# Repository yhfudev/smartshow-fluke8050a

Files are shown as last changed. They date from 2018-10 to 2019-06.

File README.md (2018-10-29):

SmartShow
=========

SmartShow implemented a digital interface to the vintage Fluke 8050a DMM,
fetches the display data via UART port, and optional connected by WiFi via an ESP8266 module.

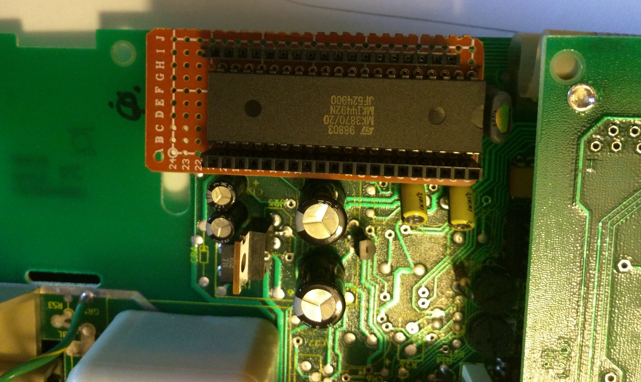
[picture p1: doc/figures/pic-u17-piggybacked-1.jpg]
Piggybacked


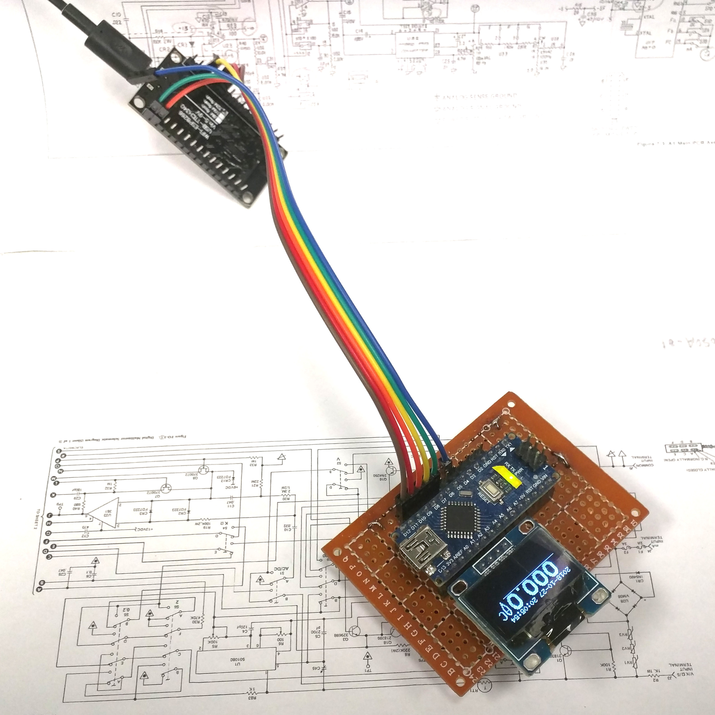
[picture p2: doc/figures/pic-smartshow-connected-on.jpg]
Connected ESP


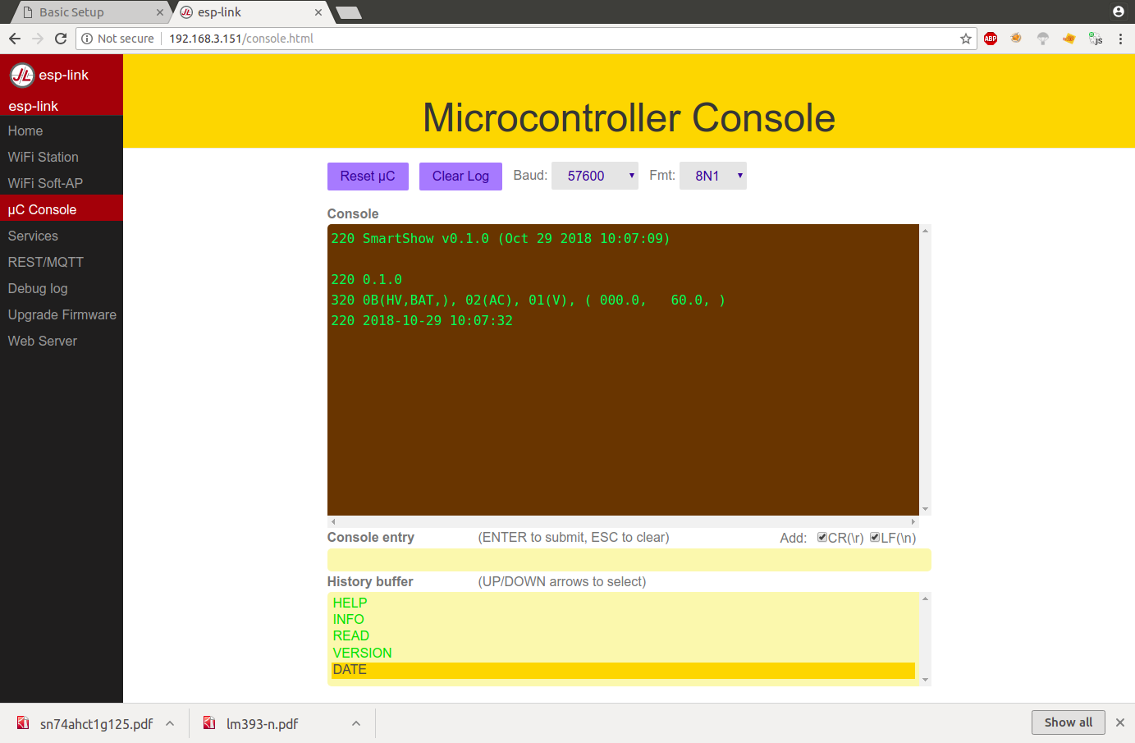
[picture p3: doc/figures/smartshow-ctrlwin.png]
Command line


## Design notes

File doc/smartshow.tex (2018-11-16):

%# -*- coding: utf-8 -*-
% !TeX encoding = UTF-8 Unicode
% !TeX spellcheck = en_US
% !TeX TS-program = xelatex
%~ \XeTeXinputencoding "UTF-8"
% vim:ts=4:sw=4
%
% 以上设定默认使用 XeLaTex 编译，并指定 Unicode 编码，供 TeXShop 自动识别

\newcommand{\doctitle}{SmarShow User Manual}
\newcommand{\docauthor}{Yunhui Fu}
\newcommand{\dockeywords}{}
\newcommand{\docsubject}{}

\documentclass[a4paper,10pt]{article}

\title{\doctitle}
\author{\docauthor}
\date{}

\usepackage{ifthen}
\usepackage{ifpdf}
\usepackage{ifxetex}
\usepackage{ifluatex}

\usepackage{url}
\usepackage{array}

\usepackage{courier}
\usepackage{listings} % list the source code

\ifxetex % xelatex
\else
    %The cmap package is intended to make the PDF files generated by pdflatex "searchable and copyable" in acrobat reader and other compliant PDF viewers.
    \usepackage{cmap}%
\fi
% ============================================
% Check for PDFLaTeX/LaTeX
% ============================================
\newcommand{\outengine}{xetex}
\newif\ifpdf
\ifx\pdfoutput\undefined
  \pdffalse % we are not running PDFLaTeX
  \ifxetex
    \renewcommand{\outengine}{xetex}
  \else
    \renewcommand{\outengine}{dvipdfmx}
  \fi
\else
  \pdfoutput=1 % we are running PDFLaTeX
  \pdftrue
  \usepackage{thumbpdf}
  \renewcommand{\outengine}{pdftex}
  \pdfcompresslevel=9
\fi
\usepackage[\outengine,
    bookmarksnumbered, %dvipdfmx
    %% unicode, %% 不能有unicode选项，否则bookmark会是乱码
    colorlinks=true,
    citecolor=red,
    urlcolor=blue,        % \href{...}{...} external (URL)
    filecolor=red,      % \href{...} local file
    linkcolor=black, % \ref{...} and \pageref{...}
    breaklinks,
    pdftitle={\doctitle},
    pdfauthor={\docauthor},
    pdfsubject={\docsubject},
    pdfkeywords={\dockeywords},
    pdfproducer={Latex with hyperref},
    pdfcreator={pdflatex},
    %%pdfadjustspacing=1,
    pdfborder=1,
    pdfpagemode=UseNone,
    pagebackref,
    bookmarksopen=true]{hyperref}

% --------------------------------------------
% Load graphicx package with pdf if needed 
% --------------------------------------------
\ifxetex    % xelatex
    \usepackage{graphicx}
\else
    \ifpdf
        \usepackage[pdftex]{graphicx}
        \pdfcompresslevel=9
    \else
        \usepackage{graphicx} % \usepackage[dvipdfm]{graphicx}
    \fi
\fi

%% \DeclareGraphicsRule{.jpg}{eps}{.bb}{}
%% \DeclareGraphicsRule{.png}{eps}{.bb}{}
\graphicspath{{./} {figures/}}
\usepackage{flafter} % 防止图形在文字前

\begin{document}

\maketitle
\tableofcontents

\section{Introduction}

SmartShow implemented a digital interface to the vintage Fluke 8050a DMM,
fetches the display data via UART port, and optional connected by WiFi via an ESP8266 module.

\section{Hardware}

\begin{figure}[h!t] \centering
    
    \caption{Fluke 8050a DMM U17.} \label{fig:fluke8050a-u17}
\end{figure}

The Arduino UNO or Micro are used as the hardware interface to the MCU of the Fluke 8050a DMM,
an ESP8266 module is used as WiFi UART bridge.

\begin{figure}[h!t] \centering
    
    \caption{ATMega328p as headless interface.} \label{fig:smartshow-atmega328p}
\end{figure}

The Arduino UNO is ATMega328p based module and have no enough pin resource to handle both the TTL signal
and an SPI LCD module, so it's only used as headless UART port for outside. While it still have the ability
to drive an I2C OLED display, and an I2C slot is reserved.

The Arduino Micro is ATMega32U4 based module, it can drive a TFT SPI display module.
So it's used to be a replacement of original Fluke 8050a LCD display.

\begin{figure}[h!t] \centering
    
    \caption{ATMega32U4 as display interface.} \label{fig:smartshow-atmega32u4}
\end{figure}

ESP8266 would not start if the TX port is connected directly or via bi-direction level shifting to the RX of Arduino UNO, the solution is to use an LM393 level shifting (Figure \ref{fig:levelshift}).

\begin{figure}[h!t] \centering
    
    \caption{Level shifting works between Arduino UNO and ESP8266.} \label{fig:levelshift}
\end{figure}

\begin{figure}[h!t] \centering
    
    \caption{ESP8266 module as WiFi UART bridge. (UART Swap mode)} \label{fig:smartshow-esp8266}
\end{figure}

\begin{figure}[h!t] \centering
    
    \caption{The connector for ESP8266.} \label{fig:smartshow-port}
\end{figure}

\begin{figure}[h!t] \centering
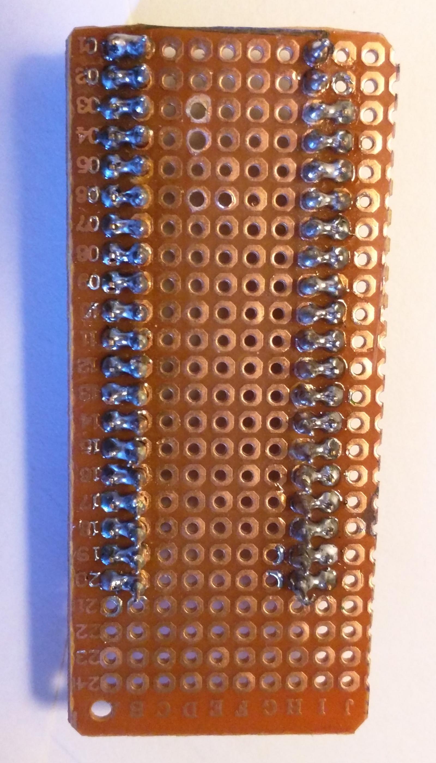
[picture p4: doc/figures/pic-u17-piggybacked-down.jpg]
    
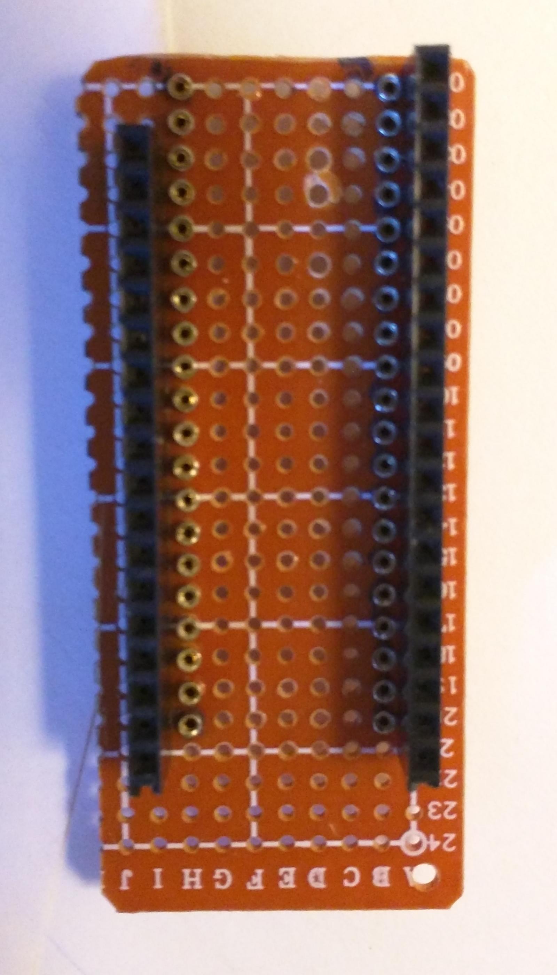
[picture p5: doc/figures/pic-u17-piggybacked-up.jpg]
    
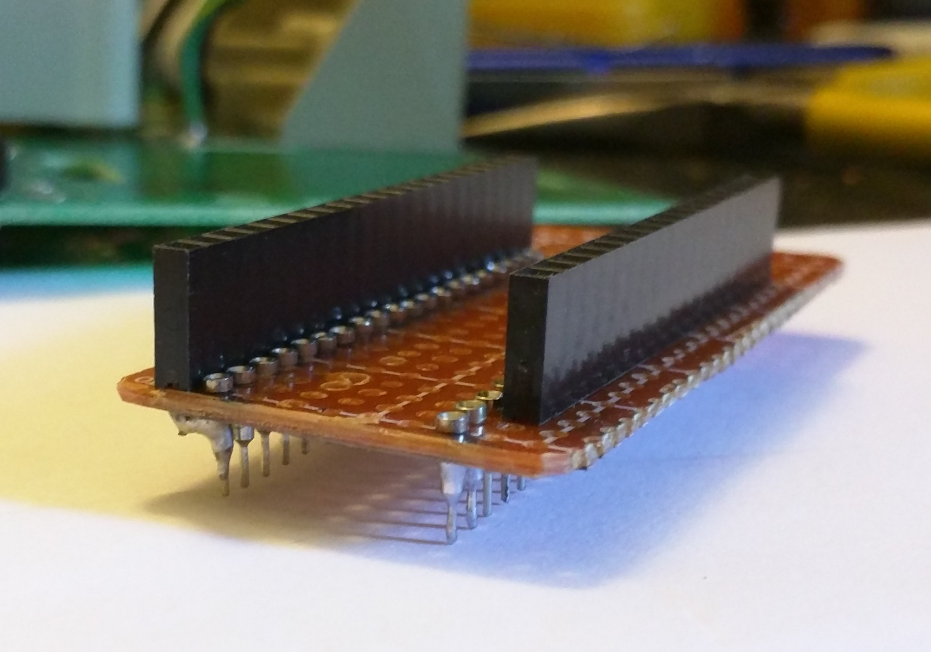
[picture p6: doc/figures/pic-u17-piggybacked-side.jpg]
    
    \caption{The Fluke8050a U17 piggybacked board.} \label{fig:picf8050apiggybrd}
\end{figure}

\begin{figure}[h!t] \centering
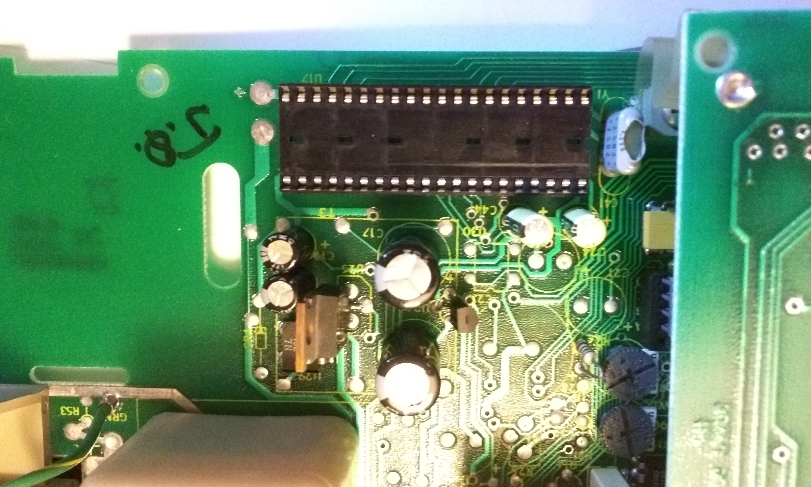
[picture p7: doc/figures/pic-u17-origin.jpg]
    
    
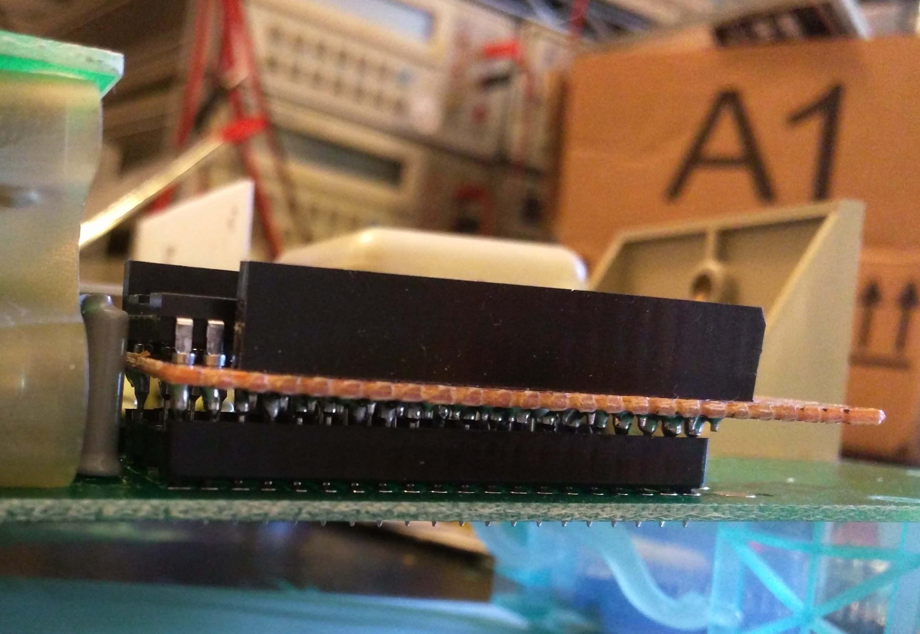
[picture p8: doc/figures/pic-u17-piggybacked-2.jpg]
    
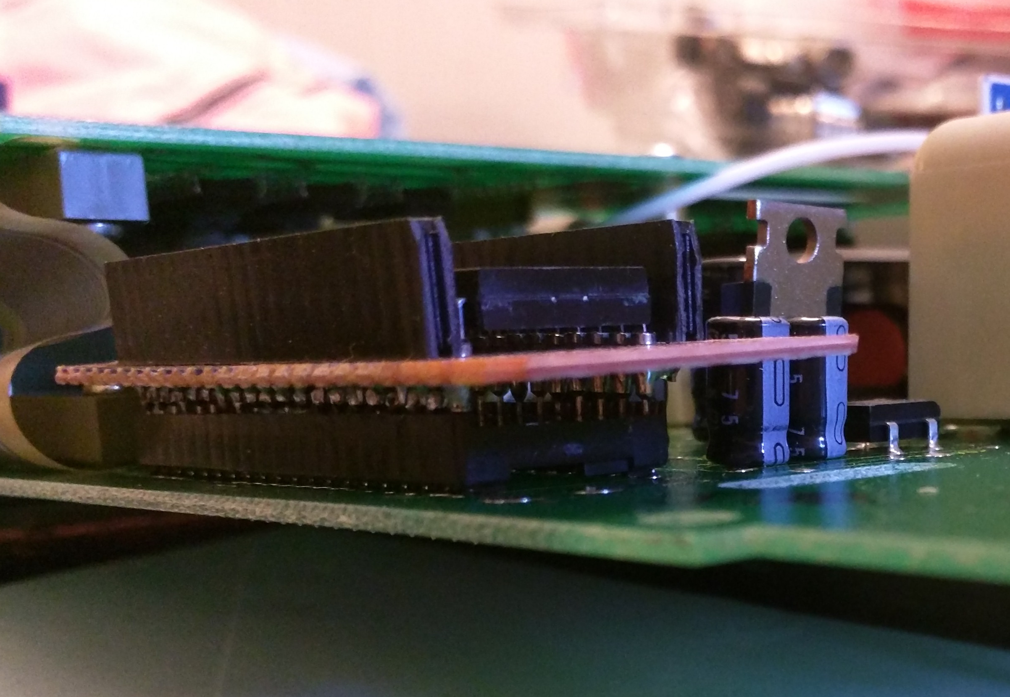
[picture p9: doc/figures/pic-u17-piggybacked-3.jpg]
    
    \caption{The Fluke8050a U17 piggybacked board installed.} \label{fig:picf8050apiggy}
\end{figure}

\begin{figure}[h!t] \centering
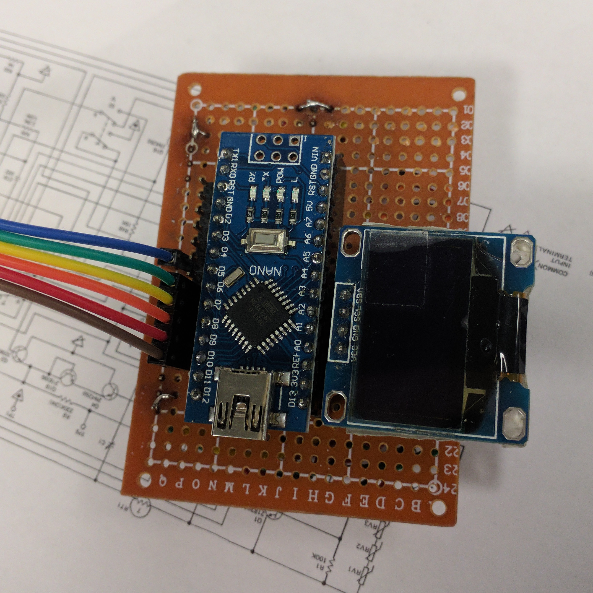
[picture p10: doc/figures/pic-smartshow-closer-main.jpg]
    
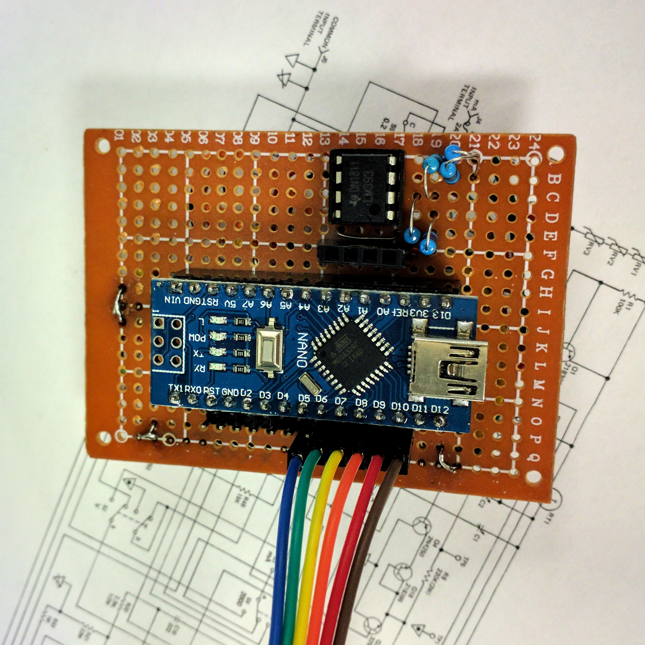
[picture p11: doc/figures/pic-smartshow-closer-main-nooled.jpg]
    
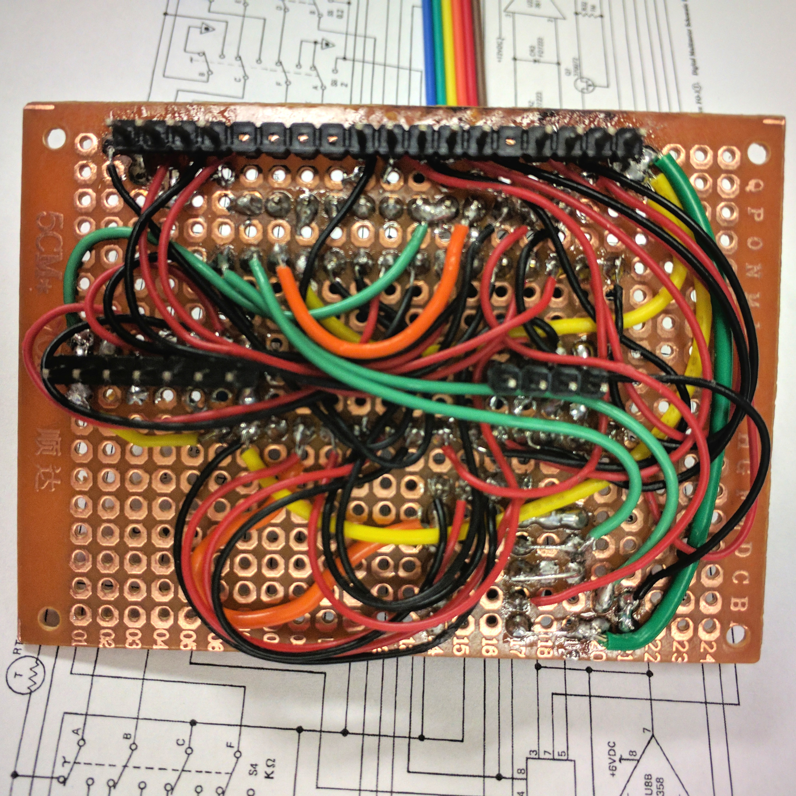
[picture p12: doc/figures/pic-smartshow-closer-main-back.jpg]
    
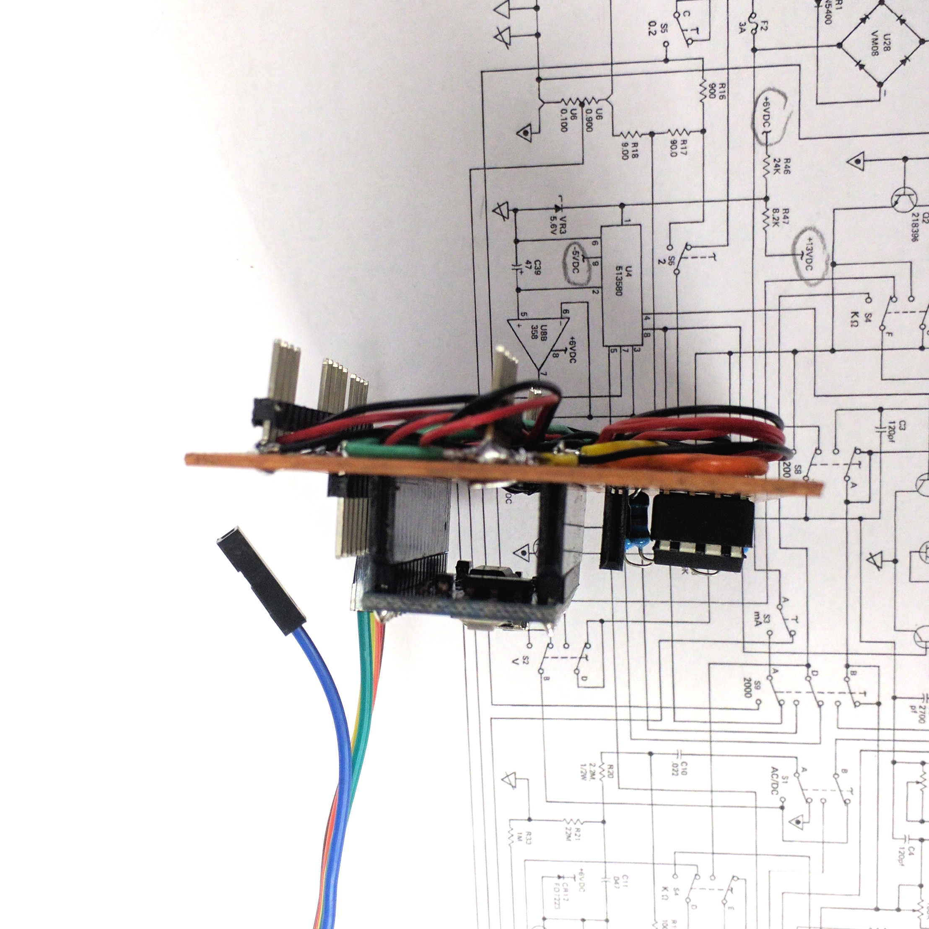
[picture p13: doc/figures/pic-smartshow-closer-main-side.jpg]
    
    \caption{The SmartShow main board.} \label{fig:picsmmain}
\end{figure}

\begin{figure}[h!t] \centering
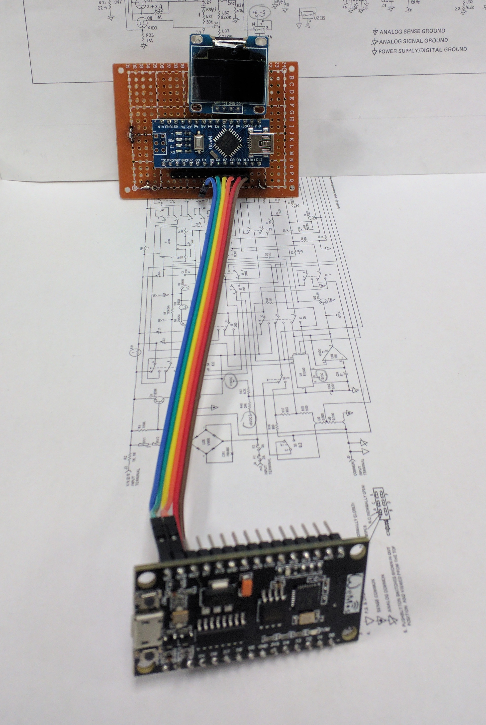
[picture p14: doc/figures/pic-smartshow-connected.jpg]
    
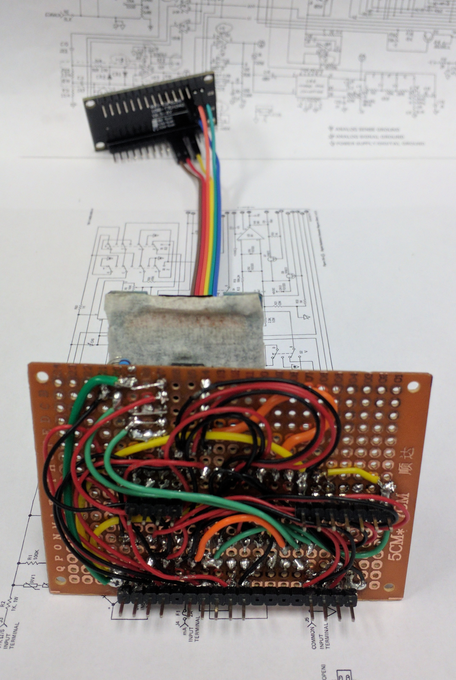
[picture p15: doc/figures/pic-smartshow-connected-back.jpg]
    
    
    \caption{The SmartShow main board connected to ESP module.} \label{fig:picsmmainconnesp}
\end{figure}

\subsection{Other Solutions}

\begin{figure}[h!t] \centering
    
    \caption{STM32(Maple-Mini).} \label{fig:smartshow-stm32}
\end{figure}

\begin{figure}[h!t] \centering
    
    \caption{Alternative level shifting.} \label{fig:levelshiftalt}
\end{figure}

\clearpage

\section{Software}

The software are for both the AVR and ESP.
The ESP can also upgrade the AVR's firmware remotely.

\subsection{Configuration}

To config the hardware used in your project, you may find the file
\texttt{conf-func.h} in the directory \texttt{software/smartshow-fluke8050a/}.

\subsection{AVR}
The AVR firmware monitor the pins \texttt{ST0, ST1, ST2, ST3, ST4, ST5} etc,
and decrypt the strobe signal to value displayed in the LCD.

The Arduino Micro Pro board needs the pins out:
\begin{lstlisting}[language=bash]
1 - pin  8 - PB0 - D17/RX LED
3 - pin 41 - PF0 - A5
5 - pin 40 - PF1 - A4
7 - pin 22 - PD5 - TX LED

2 - pin 12 - PB7 - D11
4 - pin 26 - PD6 - D12
6 - pin 32 - PC7 - D13
8 - X
\end{lstlisting}

\begin{figure}[h!t] \centering
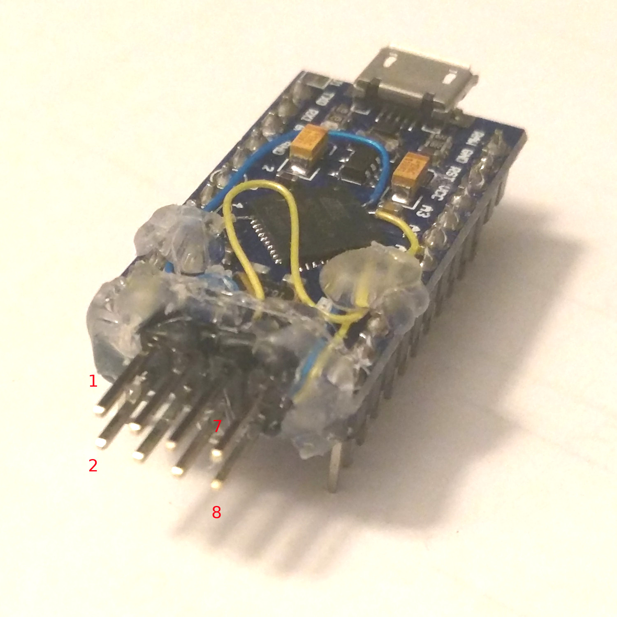
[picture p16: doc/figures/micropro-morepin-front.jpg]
    
    \caption{Pinouts of extra pins.} \label{fig:mocropropins}
\end{figure}

The strobe signal decrypt part of the source code of firmware are from the project
\href{http://vondervotteimittiss.com/belfry/?p=180}{Fluke 8050a graphic display}.

The full source project can be gotten from the repository \url{https://github.com/yhfudev/smartshow-fluke8050a.git}

\subsection{ESP}

For ESP, we use the project \href{https://github.com/jeelabs/esp-link.git}{esp-link}.
The pins are configured as showed in the Figure \ref{fig:smartshow-confwin}.

\begin{figure}[h!t] \centering
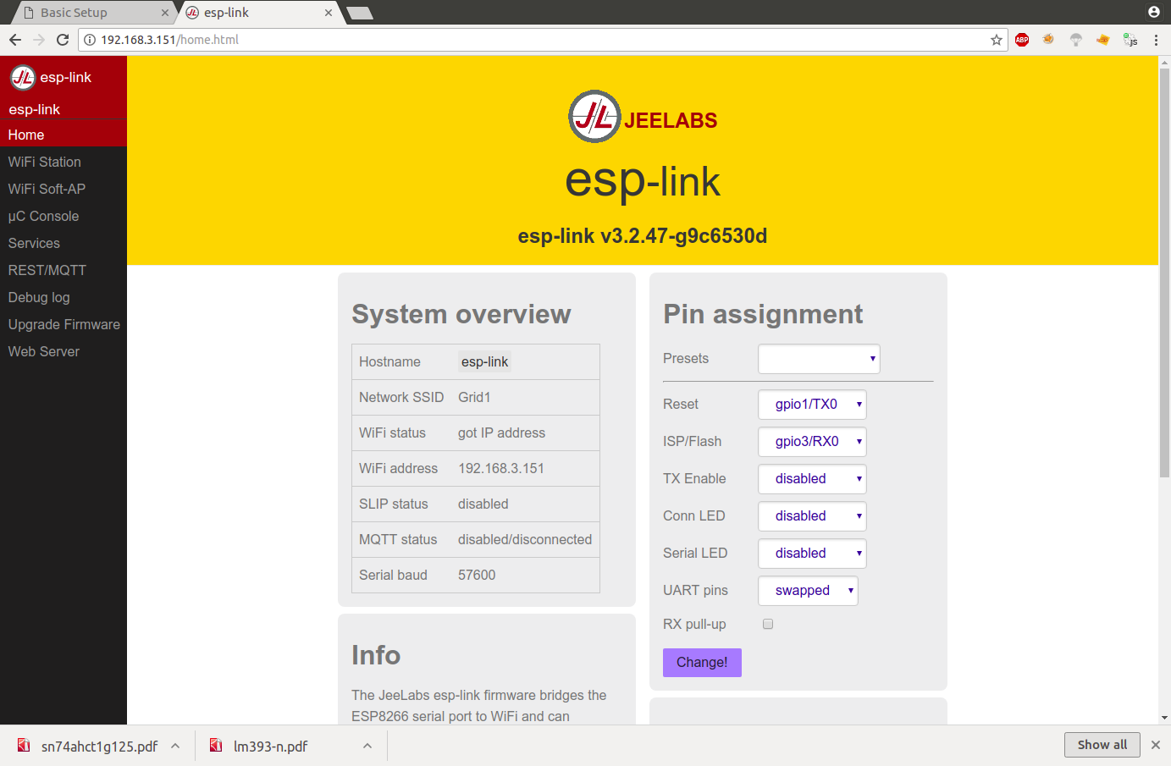
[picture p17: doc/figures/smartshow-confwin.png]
    
    \caption{Configure Pins.} \label{fig:smartshow-confwin}
\end{figure}

The data port can be accessed by either from the web UI(Figure \ref{fig:smartshow-ctrlwin}) or TCP port \texttt{23}.
\begin{figure}[h!t] \centering
    
    \caption{UART via WiFi.} \label{fig:smartshow-ctrlwin}
\end{figure}
\begin{lstlisting}[language=bash]
IP_ARDUINO=192.168.1.123
telnet ${IP_ARDUINO} 23
\end{lstlisting}

To upgrade the AVR's firmware, for example,
flash ATMega328p over Wifi:
\begin{lstlisting}[language=bash]
DN_ARDUINO="/opt/applications/arduino-1.8.5"
IP_ARDUINO=192.168.1.123
DN_HEX="/tmp/arduino_build_623246/fluke8050a-display.ino.hex"
${DN_ARDUINO}/hardware/tools/avr/bin/avrdude \
  -C${DN_ARDUINO}/hardware/tools/avr/etc/avrdude.conf \
  -v -patmega328p -carduino \
  -P  net:${IP_ARDUINO}:23 -b57600 -D -Uflash:w:${DN_HEX}:i
\end{lstlisting}

\end{document}

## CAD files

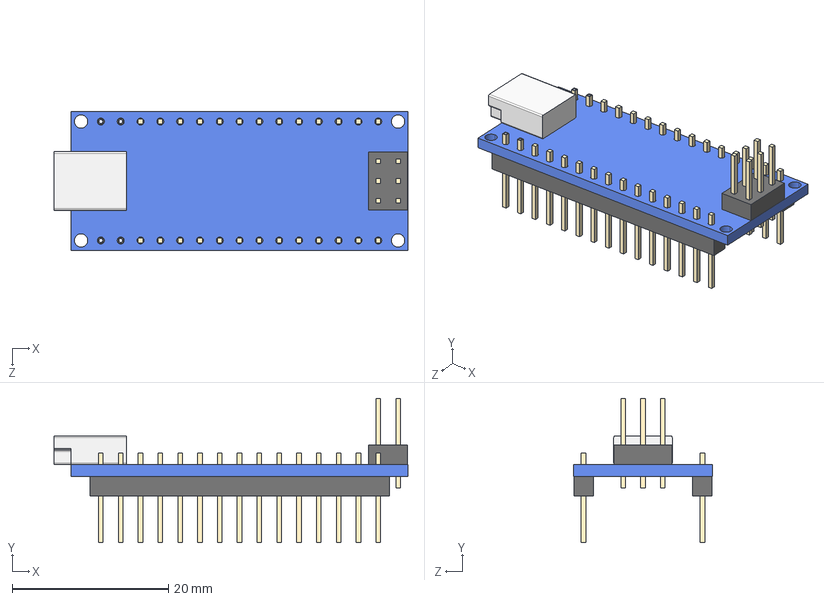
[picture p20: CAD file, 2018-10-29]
hardware/mylib/nano3.stp
45.4 x 18.5 x 17.8 mm
nano3
hdr_m15p x 2
hdr_m3x2p
usb_minib

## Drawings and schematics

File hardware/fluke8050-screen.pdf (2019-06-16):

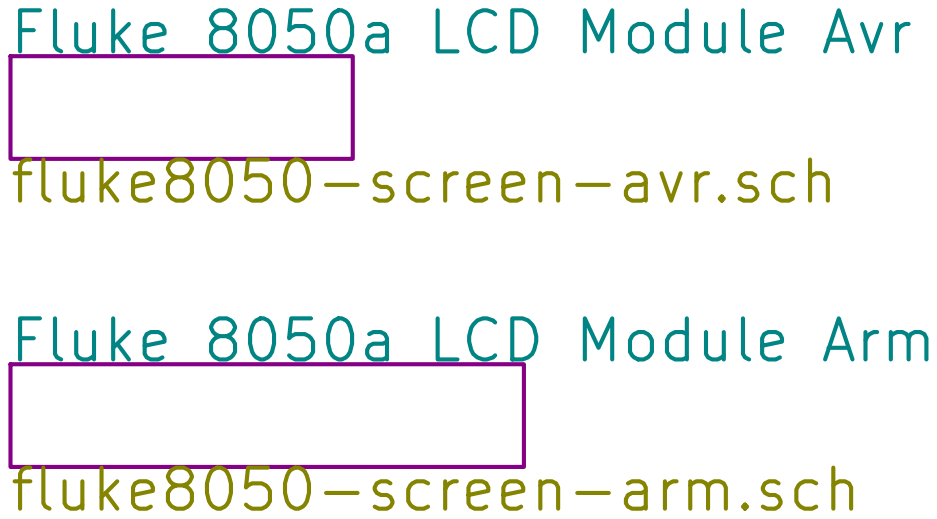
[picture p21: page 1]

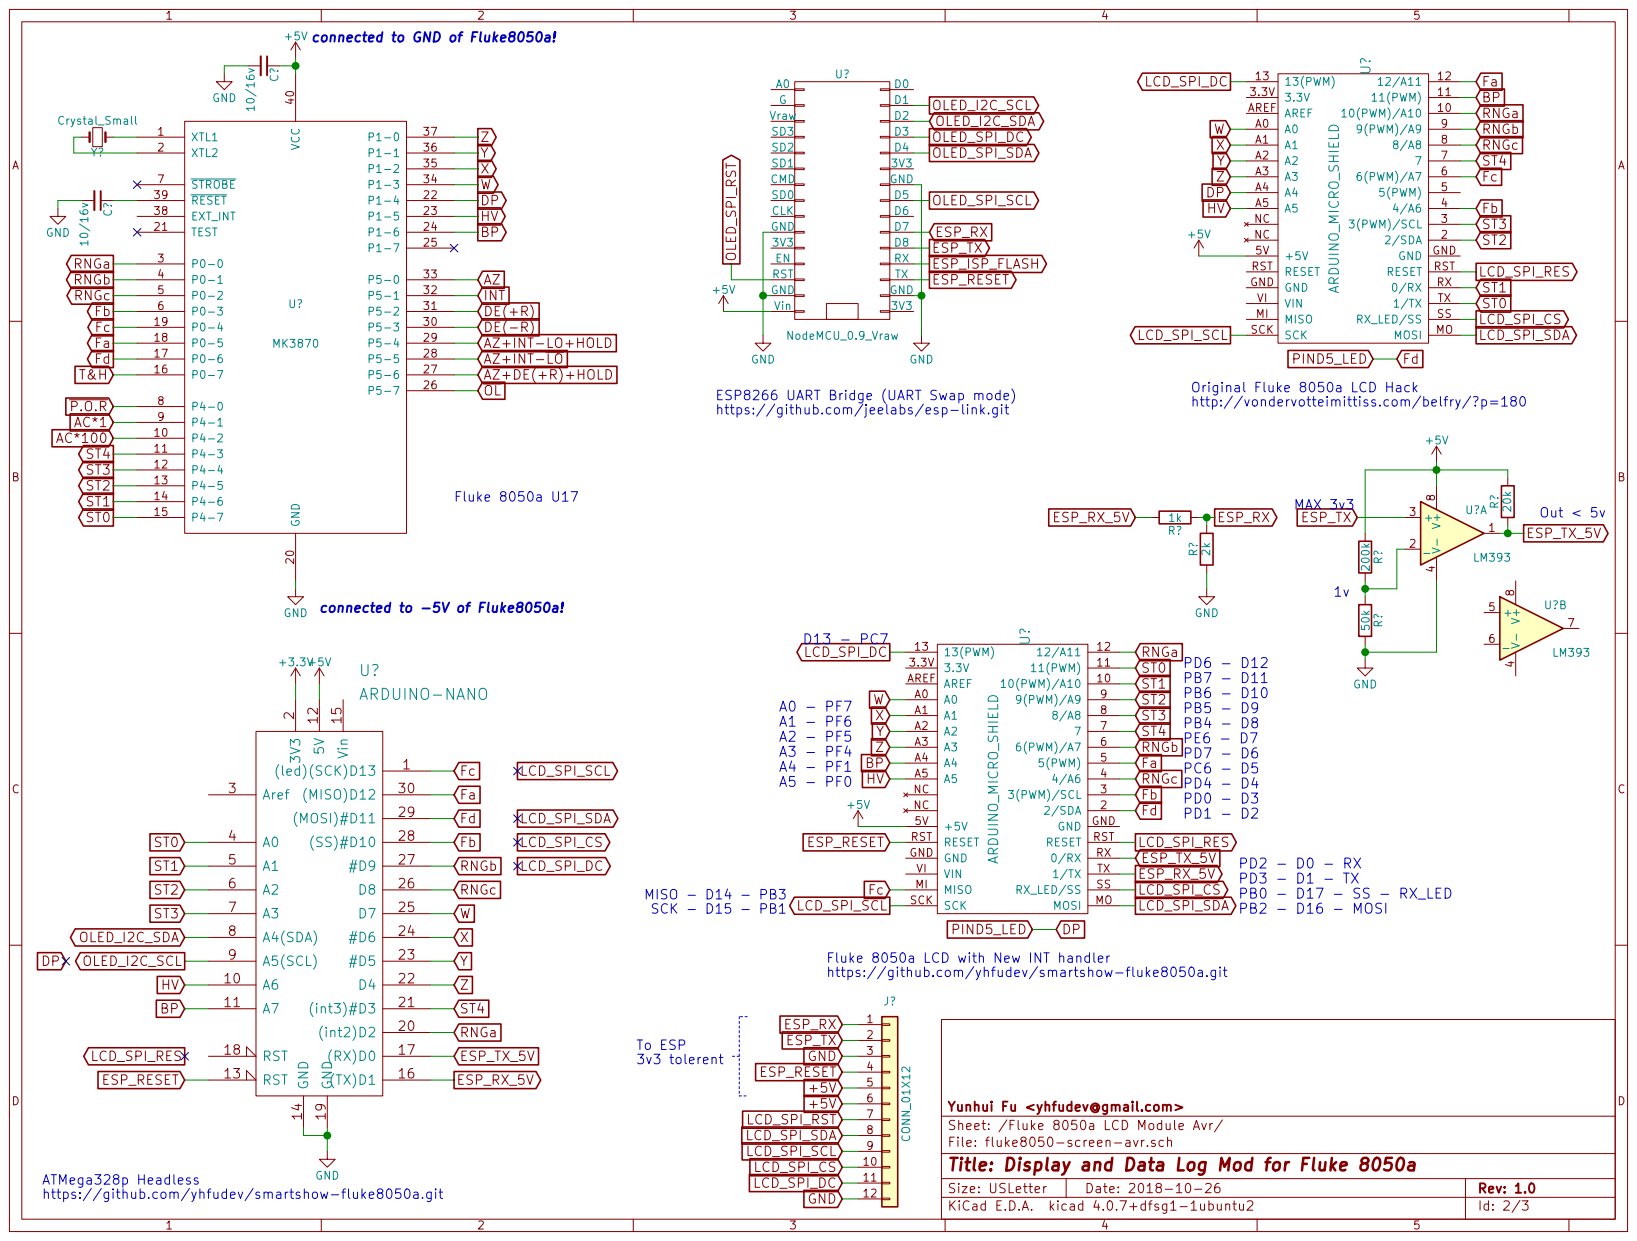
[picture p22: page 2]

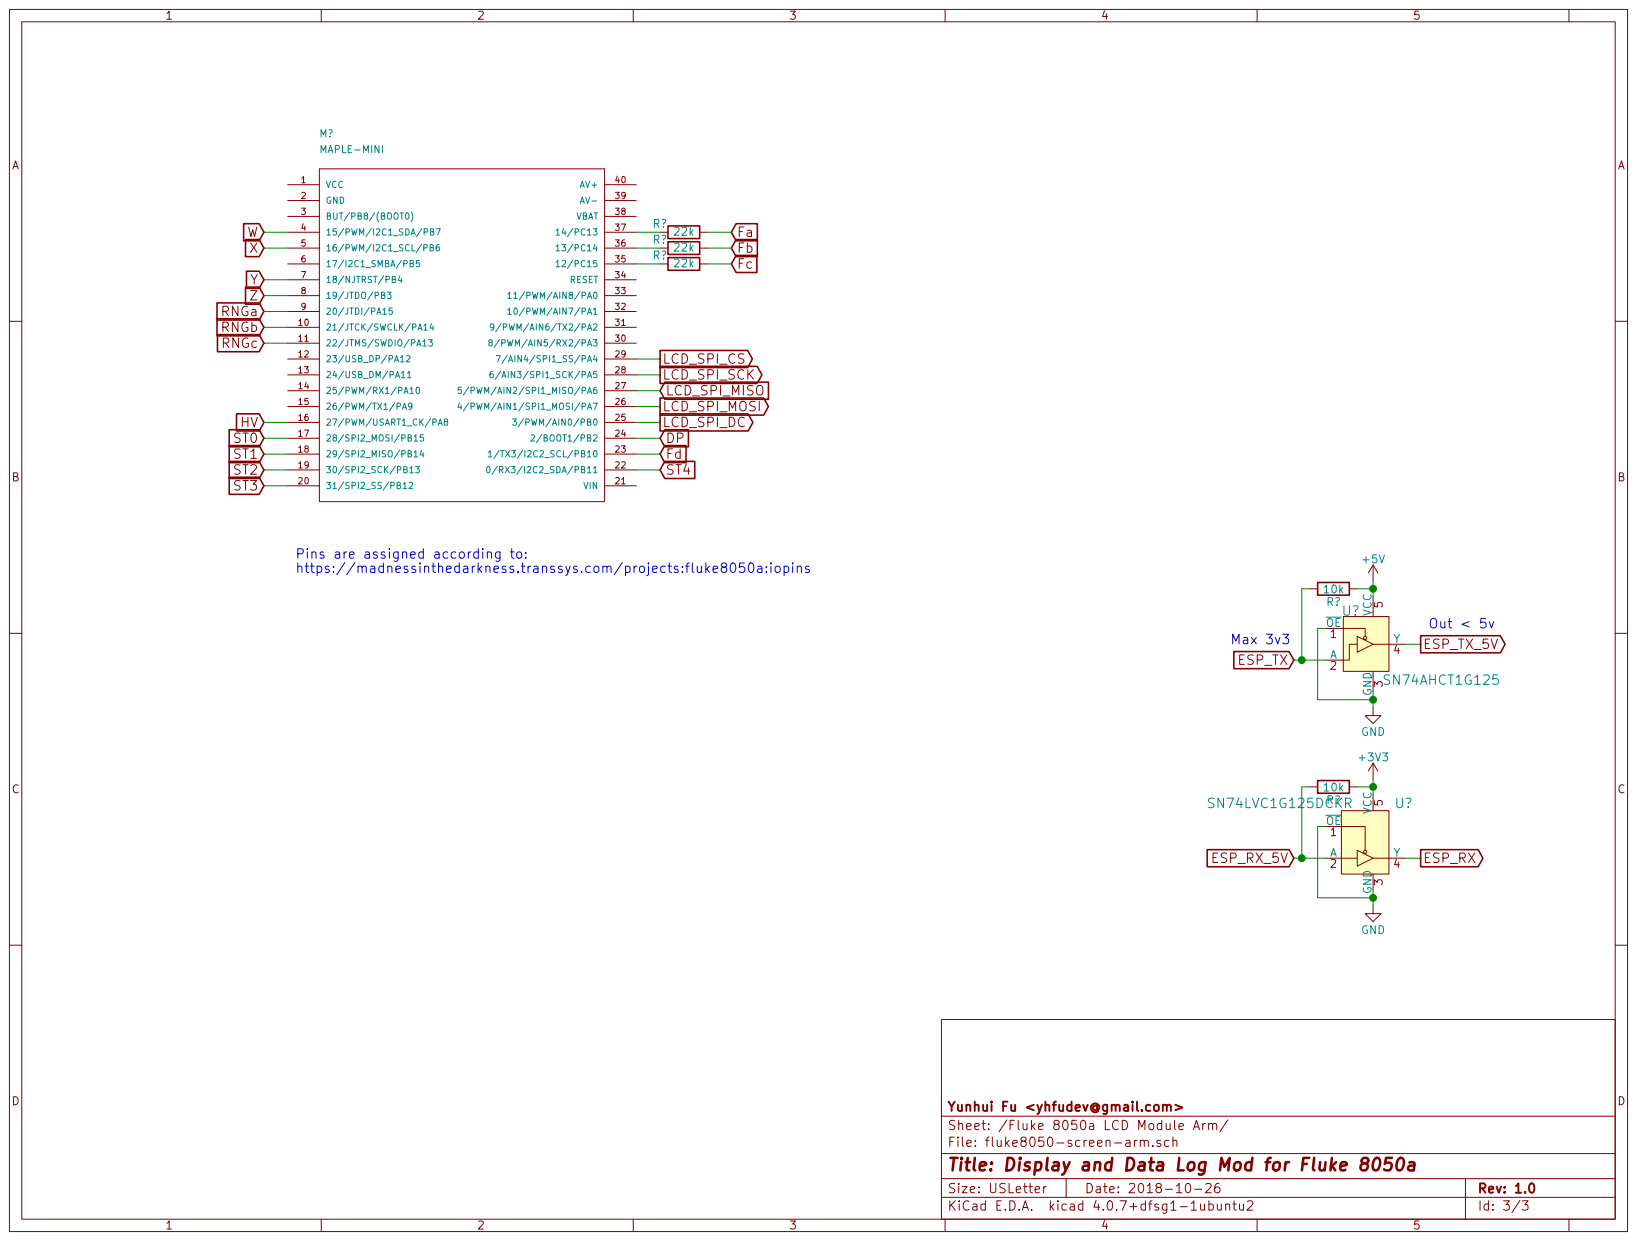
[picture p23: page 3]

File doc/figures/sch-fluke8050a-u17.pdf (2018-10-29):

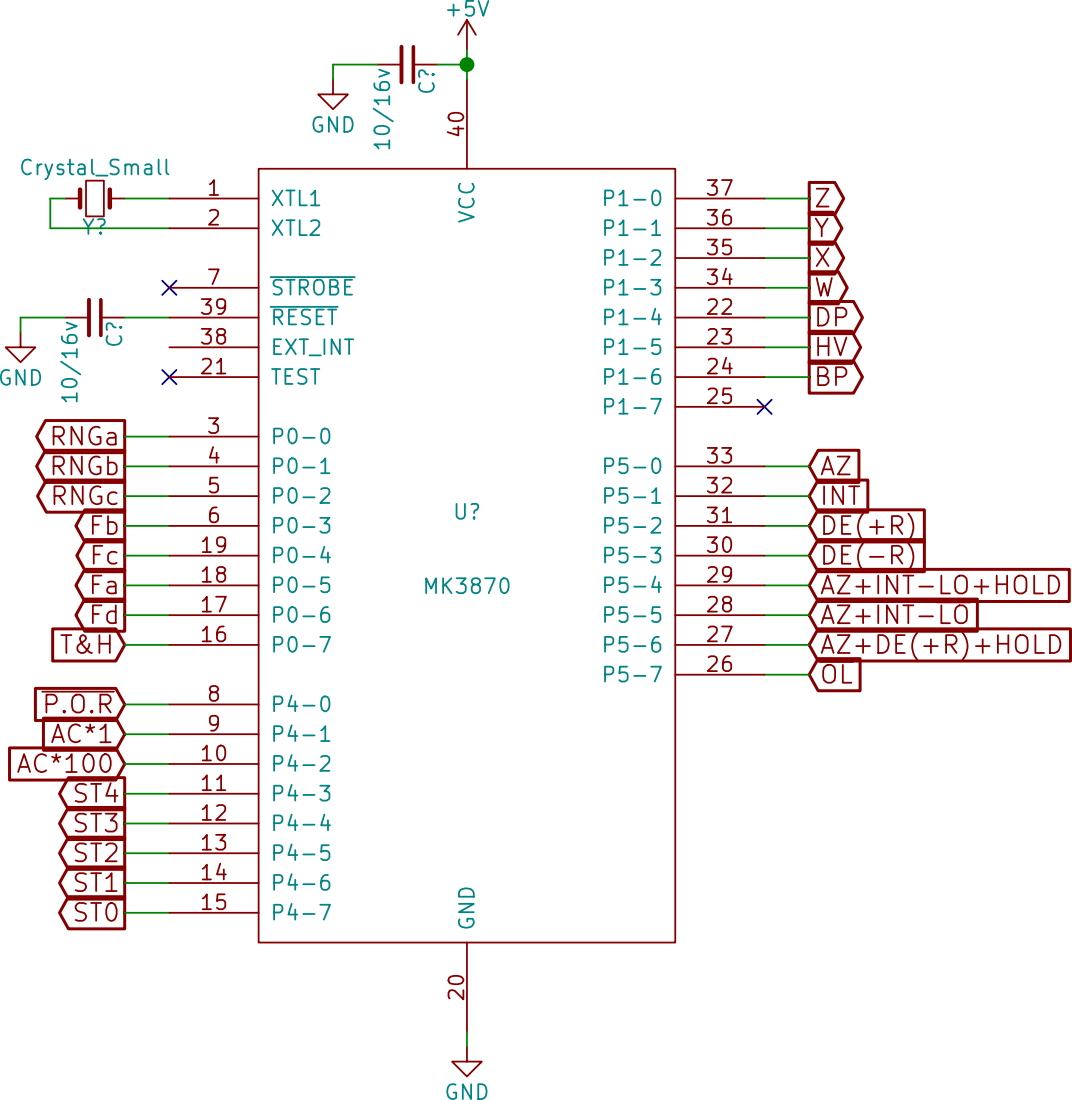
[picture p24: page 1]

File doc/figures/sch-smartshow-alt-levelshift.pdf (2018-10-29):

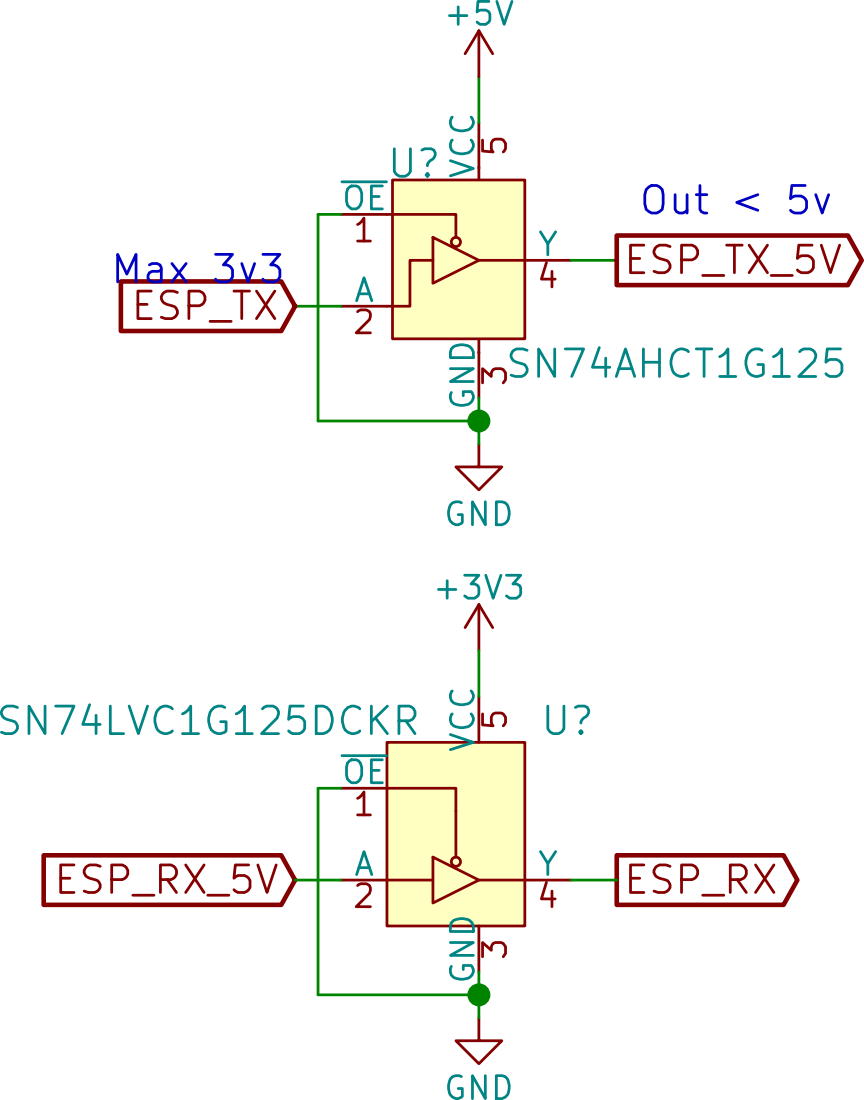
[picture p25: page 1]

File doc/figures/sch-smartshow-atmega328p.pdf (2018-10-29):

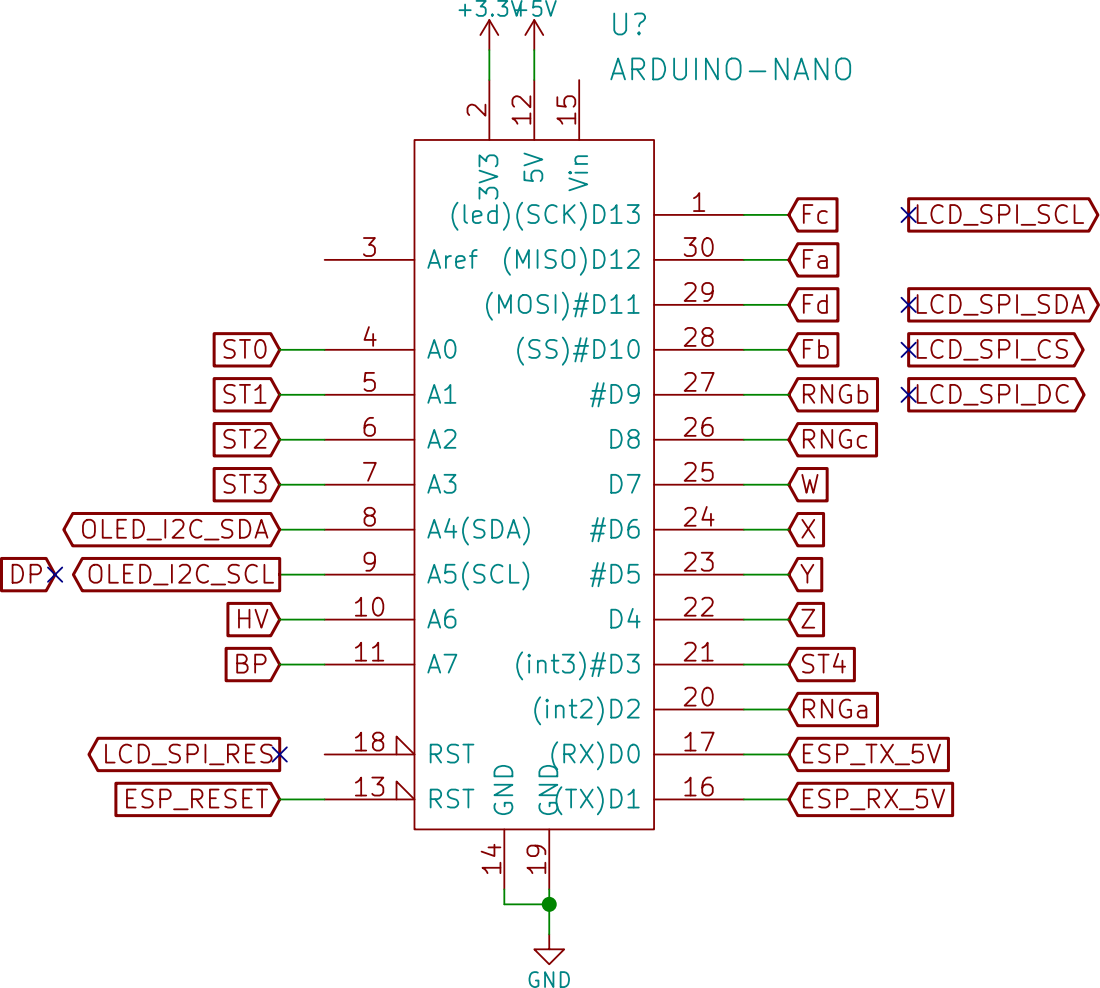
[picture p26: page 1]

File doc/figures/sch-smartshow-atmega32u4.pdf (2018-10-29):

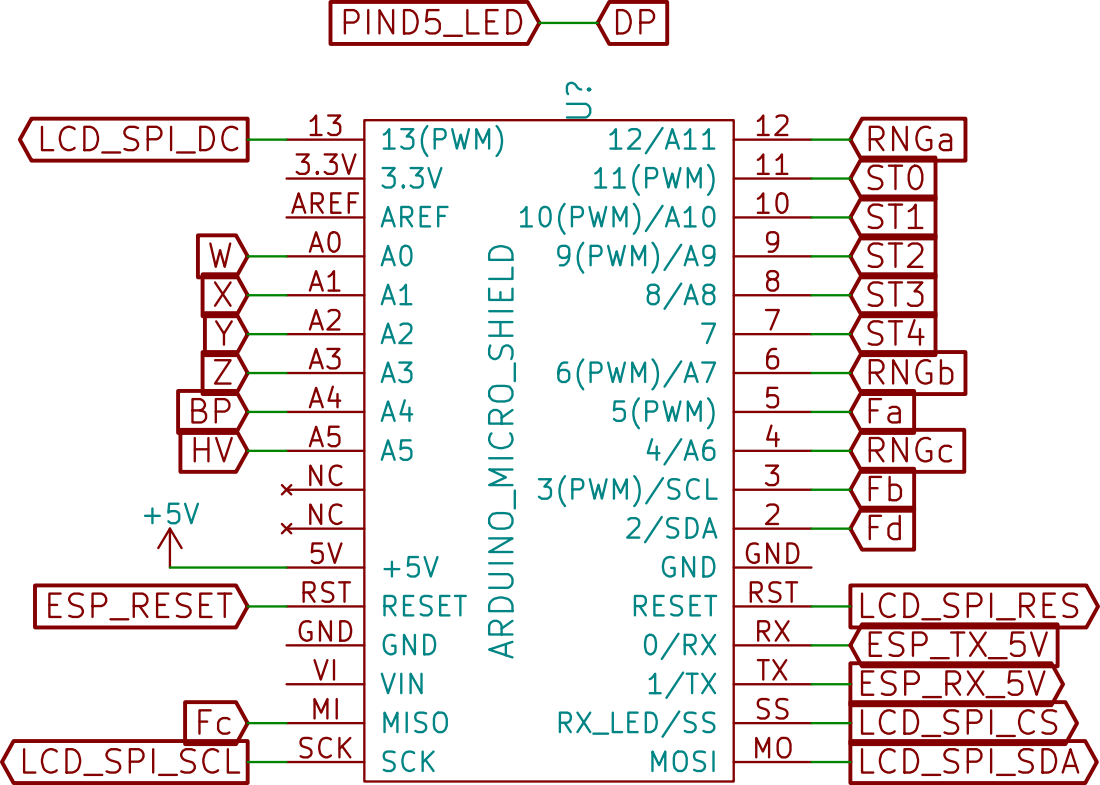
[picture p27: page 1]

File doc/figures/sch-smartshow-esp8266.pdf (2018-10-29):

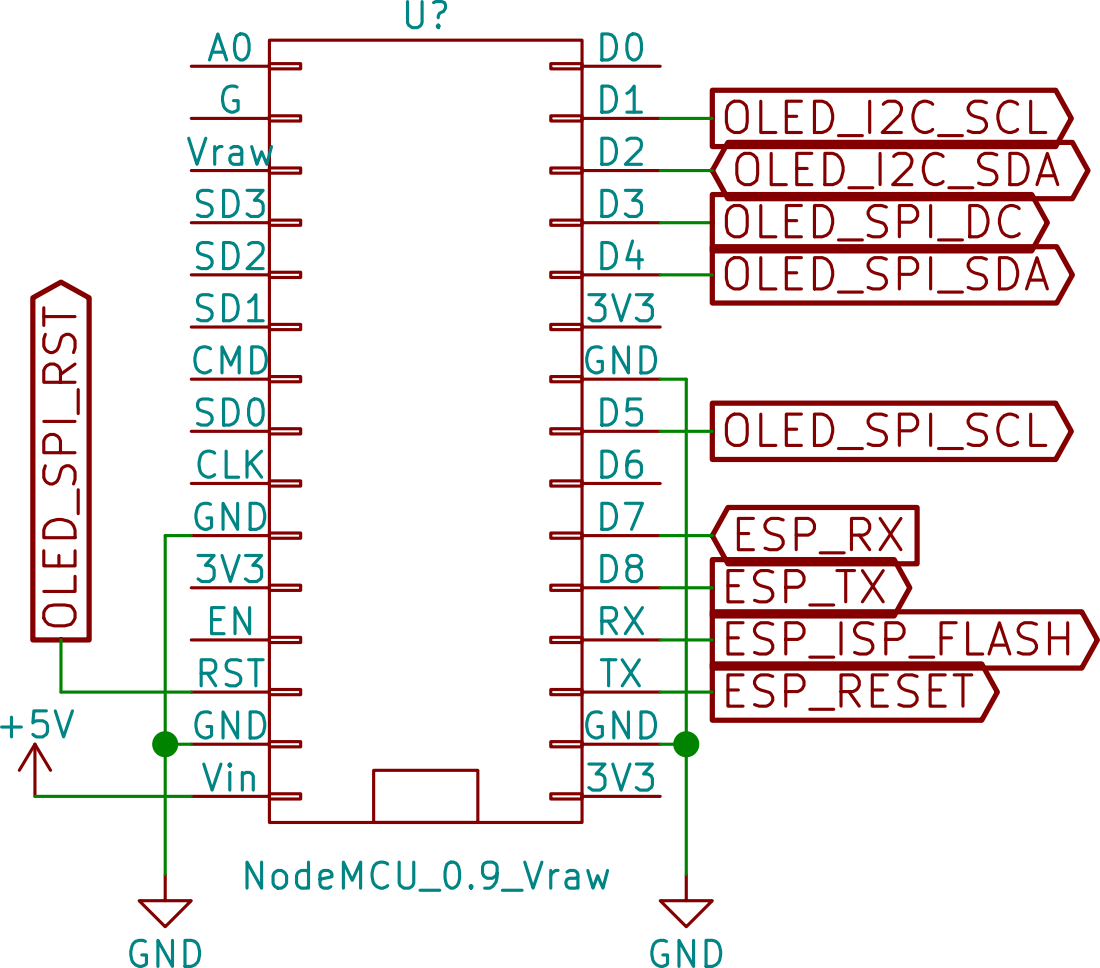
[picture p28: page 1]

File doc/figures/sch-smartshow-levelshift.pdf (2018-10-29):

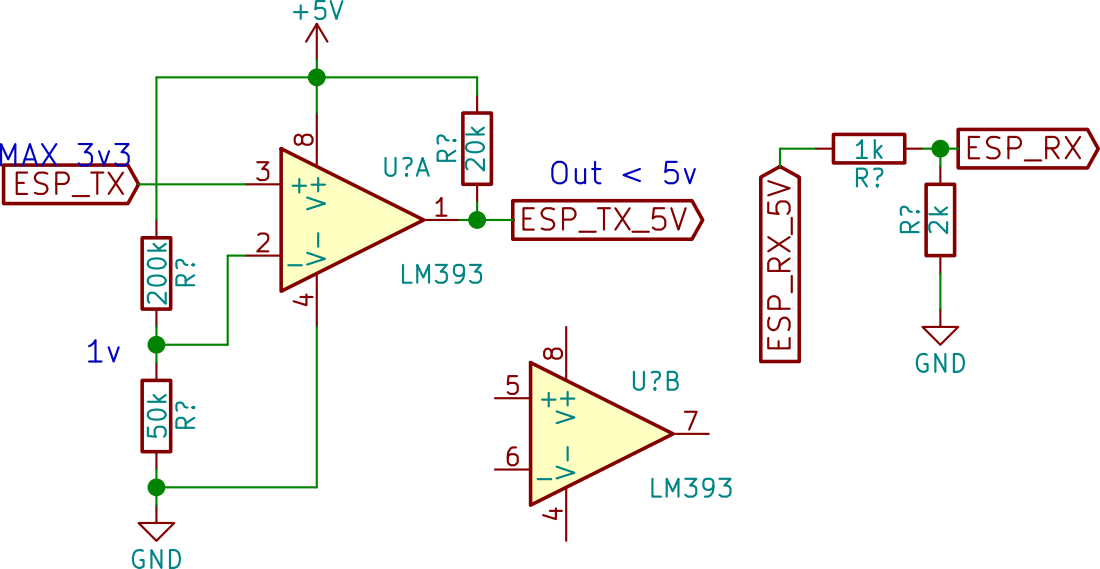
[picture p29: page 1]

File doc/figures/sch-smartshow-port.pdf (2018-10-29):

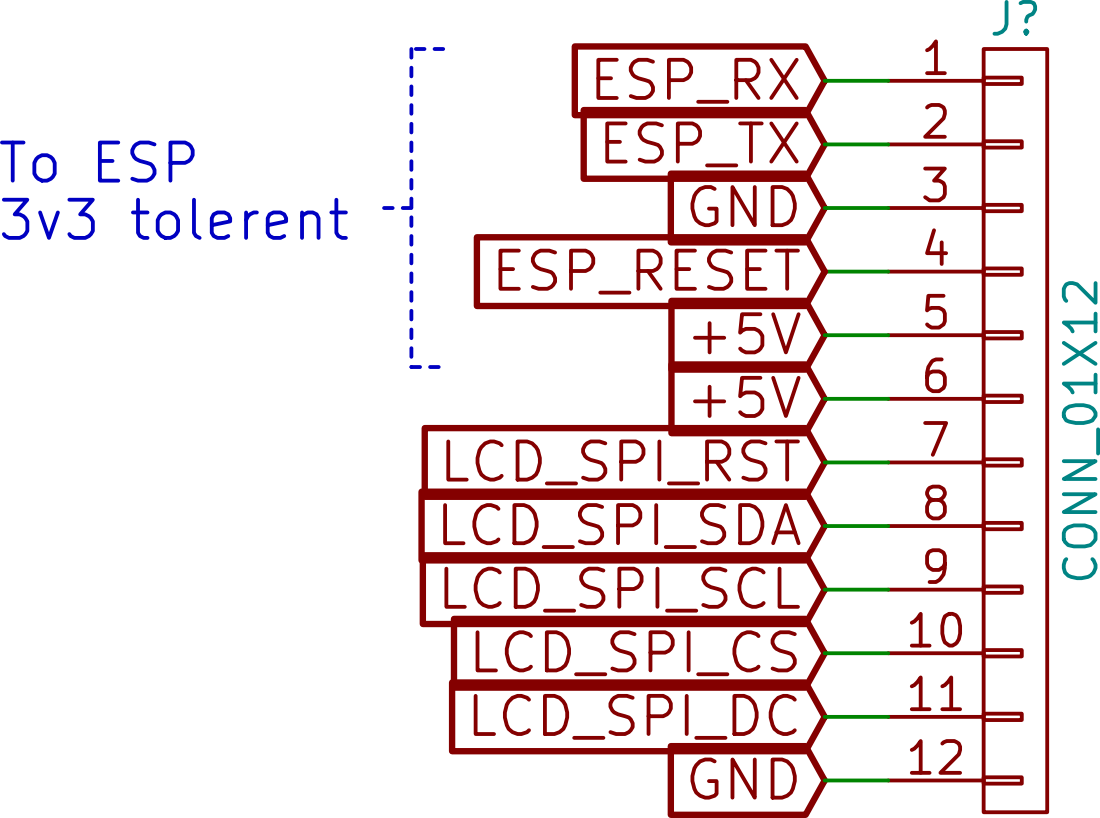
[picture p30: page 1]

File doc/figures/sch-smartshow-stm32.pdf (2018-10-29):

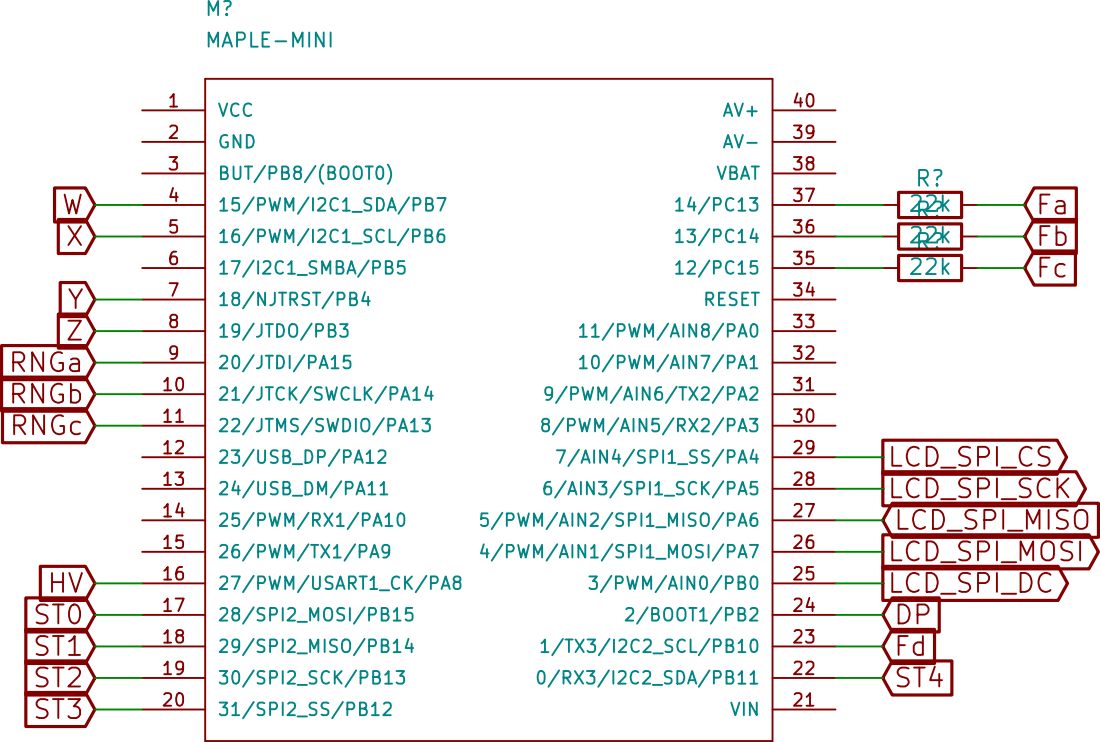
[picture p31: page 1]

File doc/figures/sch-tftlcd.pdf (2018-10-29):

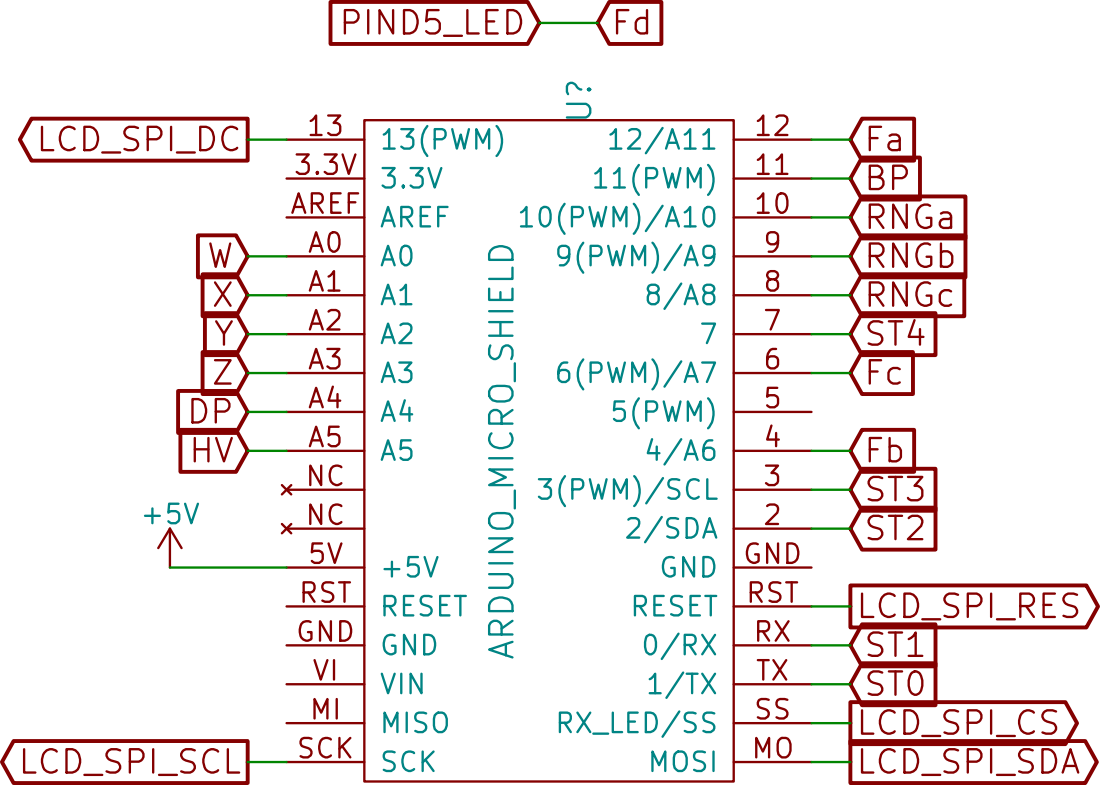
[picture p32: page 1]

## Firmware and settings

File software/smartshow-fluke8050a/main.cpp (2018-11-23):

/*
 * SmartShow SerialIP Client/Server.
 *
 * SerialIP is a TCP/IP stack that can be used over a serial port (a bit
 * like a dial-up Internet connection, but without the modem.)  It works with
 * stock Arduinos (no shields required.)  When attached to a PC supporting
 * SLIP, the Arduino can host network servers and access the Internet (if the
 * PC is configured to share its Internet connection of course!)
 *
 * SerialIP uses the fine uIP stack by Adam Dunkels <adam@sics.se>
 *
 * For more information see the SerialIP page on the Arduino wiki:
 *   <http://www.arduino.cc/playground/Code/SerialIP>
 *
 *      -----------------
 *
 * This application sets up a server at IP_HOST on port IP_PORT.
 * Telnet here to access the service.  The uIP stack will also respond to
 * pings to test if you have successfully established a SLIP connection to
 * the Arduino.
 *
 * SLIP connection set up under Linux:
 *
 *  # sudo modprobe slip
 *  # sudo slattach -L -s 57600 -p slip /dev/ttyUSB0     (see note below)
 *  # sudo ifconfig sl0 10.1.1.1 dstaddr 10.1.1.2
 *
 *  # ping 10.1.1.2
 *  # telnet 10.1.1.2 1000
 *
 * Here 10.1.1.1 is the address you will give to your PC, and it must be
 * unique on your LAN.  10.1.1.2 is the IP you will give the Arduino.  It
 * must also be unique, and must match the address the Arduino is expecting
 * as set by the "myIP" variable below.
 *
 * Note that slattach won't return so you'll need to run ifconfig from
 * another terminal.  You can press Ctrl+C to kill slattach and release the
 * serial port, e.g. to upload another sketch.
 *
 * This example was based upon uIP hello-world by Adam Dunkels <adam@sics.se>
 * Ported to the Arduino IDE by Adam Nielsen <malvineous@shikadi.net>
 */
#define VER_MAJOR 0
#define VER_MINOR 1
#define VER_REVISION 0

#define MSG_EOL "\r\n"

#include <SPI.h>
#include "conf-func.h"
#include "conf-tft.h"
#include "conf-oled.h"
#include "conf-uart.h"
#include "conf-serialip.h"
#include "fluke8050a-mcu.h"
#include "fluke8050a-show.h"
#include "TimeLib.h"

// the size of input and output buffer
#define SZ_IO_BUFFER 60 // 30
#if DEBUG
#undef  SZ_IO_BUFFER
#define SZ_IO_BUFFER 200
#endif


#ifndef __AVR__
#ifdef PSTR
#undef PSTR
#endif
#define PSTR(a) a
#endif



#ifndef __AVR__
void tft_init(void) {}
void tft_update(void) {}
void setup_mcu(void) { int a; a ++; return; }
void loop_once_mcu(void) { int a; a ++; return; }
#endif // __AVR__



int app_process_command(char * input_buffer, char * output_buffer, size_t *sz_out);
void setup_app(void);

#define C_TAB 0x09 /// TAB '\t'
#define C_LF  0x0A /// <LF> '\n'
#define C_CR  0x0D /// <CR> '\r'
#define C_BS  0x08 /// backspace '\b'

#define IS_TRIM(a) (isblank(a) || (a) == C_CR || (a) == C_LF || (a) == C_BS)

char * cstr_trim(char * dest, const char * src)
{
    char *p;
    char *p_end;

    for (p = (char *)src; IS_TRIM(*p) && (*p != 0); p ++);
    if (*p == 0) {
        dest[0] = 0;
        return dest;
    }
    p_end = p + strlen(p);
    for (; (p_end >= p) && (IS_TRIM(*(p_end-1))); p_end --);
    if (p_end == p) {
        dest[0] = 0;
        return dest;
    } else if (p != dest) {
        memmove(dest, p, (p_end - p));
    }
    return dest;
}


#if USE_SERIALIP
void uip_callback(uip_tcp_appstate_t *s);

void setup_serialip() {
  // Tell SerialIP which serial port to use (some boards have more than one.)
  // Currently this is limited to HardwareSerial ports, until both it and 
  // SoftwareSerial inherit from a common base class.
  SerialIP.use_device(SERIAL_DATA);

  // We're going to be handling uIP events ourselves.  Perhaps one day a simpler
  // interface will be implemented for the Arduino IDE, but until then...  
  SerialIP.set_uip_callback(uip_callback);

  // Set the IP address we'll be using.  Make sure this doesn't conflict with
  // any IP addresses or subnets on your LAN or you won't be able to connect to
  // either the Arduino or your LAN...
  SerialIP.begin({IP_HOST}, {IP_SUBNET});

#ifdef IP_GATEWAY
  // If you'll be making outgoing connections from the Arduino to the rest of
  // the world, you'll need a gateway set up.
  SerialIP.set_gateway({IP_GATEWAY});
#endif
}
#endif // USE_SERIALIP

static void loop_serial_read_line(void)
{
    static char m_input_buffer[SZ_IO_BUFFER];
    static char m_output_buffer[SZ_IO_BUFFER];
    static size_t m_sz_input_buffer = 0;
    int incomingByte;
    size_t sz_out = 0;
    // send data only when you receive data:
    while (SERIAL_DATA.available() > 0) {
        // read the incoming byte:
        incomingByte = SERIAL_DATA.read();
        if (incomingByte > 0) {
            m_input_buffer[m_sz_input_buffer ++] = incomingByte;
            m_input_buffer[m_sz_input_buffer] = 0;
            // TODO: check the lenght of out buffer
            if (incomingByte == '\n') {
                // call process function
                cstr_trim(m_input_buffer, m_input_buffer);
                sz_out = sizeof(m_output_buffer);
                m_output_buffer[0] = 0;
                if (app_process_command(m_input_buffer, m_output_buffer, &sz_out) < 0) {
                  // end of session
                  TD("END SESSION");
                }
                TD("sz input=%d, sz out=%d", m_sz_input_buffer, sz_out);
                m_sz_input_buffer = 0;
                if (sz_out > 0) {
                  m_output_buffer[sz_out] = 0;
                  SERIAL_DATA.print(m_output_buffer);
                }
            }
        } else {
            break;
        }
        //TD("I received: "); TD(incomingByte);
    }
}

void loop_once_serial_data() {
#if USE_SERIALIP
  // Check the serial port and process any incoming data.
  SerialIP.tick();

  // We can do other things in the loop, but be aware that the loop will
  // briefly pause while IP data is being processed.

  // ROM/RAM: 30614/1030; delta=5890/363

#else // USE_SERIALIP
  // ROM/RAM: 22804/551 (No serial)
  // ROM/RAM: 24724/667 (with serial)

  // use Serial
  loop_serial_read_line();

#endif // USE_SERIALIP
}

void setup_serial() {
  // Set up the speed of our serial link.
  SERIAL_DATA.begin(UART_BAUD); // communication port
  while( SERIAL_DATA.available() != 0 ); // flush serial buffer
  SERIAL_DEBUG.begin(UART_BAUD); // debug port
  while( SERIAL_DEBUG.available() != 0 ); // flush serial buffer

#if USE_SERVER
  // welcome message
  char m_input_buffer[11];
  char m_output_buffer[SZ_IO_BUFFER];
  size_t sz_out = sizeof(m_output_buffer);
  strcpy_P(m_input_buffer, PSTR("VERSION"));
  app_process_command(m_input_buffer, m_output_buffer, &sz_out);
  SERIAL_DEBUG.print(m_output_buffer);
  strcpy_P(m_input_buffer, PSTR("BUILDINFO"));
  app_process_command(m_input_buffer, m_output_buffer, &sz_out);
  SERIAL_DEBUG.println(m_output_buffer);
#endif
}

#ifndef NUM_ARRAY
#define NUM_ARRAY(a) (sizeof(a)/sizeof((a)[0]))
#endif

void set_time_from_built()
{
  char * month_list[] = {
    PSTR("Jan"), PSTR("Feb"), PSTR("Mar"), PSTR("Apr"),
    PSTR("May"), PSTR("Jun"), PSTR("Jul"), PSTR("Aug"),
    PSTR("Sep"), PSTR("Oct"), PSTR("Nov"), PSTR("Dec"),
  };
  // set the current time to the built time
  char buf_date[] = __DATE__;
  char buf_time[] = __TIME__;
  int yr = 2000;
  int mo = 1;
  int dy = 1;
  int hr = 0;
  int mt = 0;
  int sc = 0;
  char *p;

  p = buf_date;
  for(int i = 0; i < NUM_ARRAY(month_list); i ++) {
    if (0 == strncmp_P(p, month_list[i], 3)) {
      mo = i + 1;
      break;
    }
  }
  p = strchr(p, ' ');
  if (p) {
    p ++;
    dy = atoi(p);
  }
  p = strchr(p, ' ');
  if (p) {
    p ++;
    yr = atoi(p);
  }
  hr = atoi(buf_time);
  mt = atoi(buf_time + 3);
  sc = atoi(buf_time + 6);
  setTime(hr, mt, sc, dy, mo, yr);
}


void setup() {
  setup_serial();
  set_time_from_built();

#if USE_SERIALIP
  setup_serialip();
  setup_app();
#endif
#if USE_TTF || USE_OLED
  tft_init();
#endif
  setup_mcu();
}

void loop() {
  loop_once_serial_data();
  loop_once_mcu();
#if USE_TTF || USE_OLED
  tft_update();
#endif
}

#if USE_SERVER
// server
typedef struct _app_data_t {
    uint8_t state; // 0 - init, 1 - normal, 2 - quit
    char input_buffer[SZ_IO_BUFFER];
    char output_buffer[SZ_IO_BUFFER];
} app_data_t;

// process command string in the input_buffer, and output the result in the output_buffer
// return the size of content in the output_buffer via sz_out
int
app_process_command(char * input_buffer, char * output_buffer, size_t *sz_out)
{
    char flg_time = 0;
    char flg_quit = 0;

//#define CSTR_HAS_HEADER(cstr, buf) (0 == strcasecmp_P(buf, PSTR(cstr))) // failed
//#define CSTR_HAS_HEADER(cstr, buf) (0 == strcasecmp_P(PSTR(cstr), buf)) // failed
#define CSTR_HAS_HEADER(cstr, buf) (0 == strncmp_P(buf, PSTR(cstr), sizeof(cstr)-1)) // OK
//#define CSTR_HAS_HEADER(cstr,buf) (0 == strncmp(buf, (cstr), sizeof(cstr)-1)) // OK

    output_buffer[0] = 0;

    flg_time = 0;
    if (strlen(input_buffer) == 0) {
        // ignore

#define CSTR_COMMAND "READ"
    } else if (CSTR_HAS_HEADER(CSTR_COMMAND, input_buffer)) {
        // test
        fluke8050a_reads_t mcudata;
        if (0 == fluke8050a_get_data(&mcudata)) {
            strcpy_P(output_buffer, PSTR("320 "));
            fluke8050a_reads2desc(&mcudata, output_buffer + strlen(output_buffer), *sz_out - strlen(output_buffer));
            strcat_P(output_buffer, PSTR(MSG_EOL));
        } else {
            strcpy_P(output_buffer, PSTR("520 MCU error" MSG_EOL));
        }
#undef CSTR_COMMAND

#if 0
#define CSTR_COMMAND "HELO"
    } else if (CSTR_HAS_HEADER(CSTR_COMMAND, input_buffer)) {
        //TD("print version");
        snprintf_P(output_buffer, *sz_out
            , PSTR("220 ready %d.%d.%d" MSG_EOL)
            , VER_MAJOR, VER_MINOR, VER_REVISION);
        //TD("end print version");
#undef CSTR_COMMAND
#endif // 0

#define CSTR_COMMAND "VERSION"
    } else if (CSTR_HAS_HEADER(CSTR_COMMAND, input_buffer)) {
        //TD("print version");
        snprintf_P(output_buffer, *sz_out
            , PSTR("220 SmartShow v%d.%d.%d (" __DATE__ " " __TIME__ ")" MSG_EOL)
            , VER_MAJOR, VER_MINOR, VER_REVISION);
        //TD("end print version");
#undef CSTR_COMMAND

#define CSTR_COMMAND "BUILDINFO"
    } else if (CSTR_HAS_HEADER(CSTR_COMMAND, input_buffer)) {
        //TD("print information");
        snprintf_P(output_buffer, *sz_out
            , PSTR("220 Conf: "
#if DEBUG
                "DBG"
#else
                "REL"
#endif
#if USE_MCUFONT
                ",mcufont"
#endif
#if USE_U8G
                ",u8glib"
#else
                ",AdafruitGfx"
#endif
#if USE_OLED
                ",OLED"
#else
                ",TFT"
  #if USE_TFT_ST7735
                ",ST7735"
  #elif USE_TFT_ILI9340H
                ",ILI9340H"
  #elif USE_TFT_ILI9341
                ",ILI9341"
  #endif
#endif
                MSG_EOL
              )
            );
        //TD("end print version");
#undef CSTR_COMMAND

#define CSTR_COMMAND "UNXTIME"
    } else if (CSTR_HAS_HEADER(CSTR_COMMAND, input_buffer)) {
      long unixTime = 0;
      if (strlen(input_buffer) > sizeof(CSTR_COMMAND)) {
        // set the unix time
        // if data sent is the UNX token, take it
        unixTime = atol(input_buffer + sizeof(CSTR_COMMAND));

        // Synchronize the time with the internal clock
        // for external use RTC.setTime();
      }
      if (unixTime > 0) {
        setTime(unixTime);
        flg_time = 1;
      } else {
        snprintf_P(output_buffer, *sz_out, PSTR("200 %lu" MSG_EOL), now());
      }

#define CSTR_COMMAND "DATE"
    } else if (CSTR_HAS_HEADER(CSTR_COMMAND, input_buffer)) {
      if (strlen(input_buffer) > sizeof(CSTR_COMMAND)) {
        // set the unix time
        int yr = 0;
        int mo = 0;
        int dy = 0;
        int hr = 0;
        int mt = 0;
        int sc = 0;
#if 0
        if (6 == sscanf_P(input_buffer + sizeof(CSTR_COMMAND), "%d-%d-%d %d:%d:%d", &yr, &mo, &dy, &hr, &mt, &sc)) {
          setTime(hr,mt, sc, dy, mo, yr);
        }
#else
        // reduce the size
        char *p = input_buffer + sizeof(CSTR_COMMAND) - 1;
        do {
        // scan date
        if (p) {yr = atoi(++p); p = strchr(p+1, '-'); }
        if (p) {mo = atoi(++p); p = strchr(p+1, '-'); } else { break; }
        if (p) {dy = atoi(++p); p = strchr(p+1, ' '); } else { break; }
        if (p) {hr = atoi(++p); p = strchr(p+1, ':'); } else { hr = hour(); }
        if (p) {mt = atoi(++p); p = strchr(p+1, ':'); } else { mt = minute(); }
        if (p) {sc = atoi(++p); } else { sc = second(); }
        setTime(hr, mt, sc, dy, mo, yr);
        } while (0);
#endif
      }
      flg_time = 1;
#undef CSTR_COMMAND

#define CSTR_COMMAND "QUIT"
    } else if ( CSTR_HAS_HEADER(CSTR_COMMAND, input_buffer) || CSTR_HAS_HEADER("EXIT", input_buffer)) {
        flg_quit = 1; // quit
        strcpy_P(output_buffer, PSTR("200 BYE" MSG_EOL));

#if 0 // defined(USE_TTF) && USE_TTF
#define CSTR_COMMAND "TFT"
    } else if (CSTR_HAS_HEADER(CSTR_COMMAND, input_buffer)) {
      if (strlen(input_buffer) > sizeof(CSTR_COMMAND)) {
        int type = atoi(input_buffer + sizeof(CSTR_COMMAND));
        tft_type(type);
      }
      strcpy_P(output_buffer, PSTR("220 TFT" MSG_EOL));

#undef CSTR_COMMAND
#endif // USE_TFT

#define CSTR_COMMAND "HELP"
    } else if (CSTR_HAS_HEADER(CSTR_COMMAND, input_buffer)) {
      strcpy_P(output_buffer, PSTR("220 Supported commands: READ, BUILDINFO, VERSION, DATE, UNXTIME, QUIT" MSG_EOL));
#undef CSTR_COMMAND

    } else {
        snprintf_P(output_buffer, *sz_out
            , PSTR("501 unknown: '%s'" MSG_EOL)
            , input_buffer);
    }

    if(flg_time) {
      snprintf_P(output_buffer, *sz_out
          , PSTR("220 %d-%02d-%02d %02d:%02d:%02d" MSG_EOL)
          , year(), month(), day(), hour(), minute(), second());
    }
    //TD("outbuffer size=%d; outbuffer=%s", strlen(output_buffer), output_buffer);
    *sz_out = strlen(output_buffer);
    if (flg_quit) {
        return -2;
    }
    return 0;
}

#if USE_SERIALIP
// This function is going to use uIP's protosockets to handle the connection.
// This means it must return int, because of the way the protosockets work.
// In a nutshell, when a PSOCK_* macro needs to wait for something, it will
// return from handle_connection so that other work can take place.  When the
// event is triggered, uip_callback() will call this function again and the
// switch() statement (see below) will take care of resuming execution where
// it left off.  It *looks* like this function runs from start to finish, but
// that's just an illusion to make it easier to code :-)
int handle_connection(uip_tcp_appstate_t *s, app_data_t *d)
{
  size_t sz_out;
  // All protosockets must start with this macro.  Its internal implementation
  // is that of a switch() statement, so all code between PSOCK_BEGIN and
  // PSOCK_END is actually inside a switch block.  (This means for example,
  // that you can't declare variables in the middle of it!)
  PSOCK_BEGIN(&s->p);

  // welcome message
  // Send some text over the connection.
  PSOCK_SEND_STR(&s->p, "220 ready\n");
  d->state = 1;

  while (d->state < 2) {
    //TD("SERVE ...");
    // Read some returned text into the input buffer we set in PSOCK_INIT.  Data
    // is read until a newline (\n) is received, or the input buffer gets filled
    // up.  (Which, at 16 chars by default, isn't hard!)
    memset(d->input_buffer, 0, sizeof(d->input_buffer));
    PSOCK_READTO(&s->p, '\n');
    //d->input_buffer[PSOCK_DATALEN(&s->p)] = 0;
    //TD("recv:");TD(d->input_buffer);

    // Since any subsequent PSOCK_* functions would overwrite the buffer, we
    // need to make a copy of it first.  We can't use a local variable for this,
    // because any PSOCK_* macro may make the function return and resume later,
    // thus losing the data in any local variables.  This is why uip_callback
    // has allocated the app_data_t structure for us to use instead.  (You
    // can add/remove other variables in this struct to store different data.
    // See the other file in this sketch, serialip_conn.h)

    // Note that this will misbehave when the input buffer overflows (i.e.
    // more than 16 characters are typed in) but hey, this is supposed to be
    // a simple example.  Fixing this problem will be left as an exercise for
    // the reader :-)
    cstr_trim(d->input_buffer, d->input_buffer);
    sz_out = sizeof(d->output_buffer);
    if (app_process_command(d->input_buffer, d->output_buffer, &sz_out) < 0) {
      d->state = 2;
    }
    if (sz_out > 0) {
      //TD("RESPONSE ...");
      PSOCK_SEND_STR(&s->p, d->output_buffer);
    }
  }

  //TD("CLOSE ...");
  PSOCK_CLOSE(&s->p);

  // All protosockets must end with this macro.  It closes the switch().
  PSOCK_END(&s->p);
}

void setup_app(void)
{
  // Listen for incoming connections on TCP port IP_PORT.  Each incoming
  // connection will result in the uip_callback() function being called.
  SerialIP.listen(IP_PORT);

  //TD("listen to: 1000");
  //TD("addr: 10.1.1.2");
}

void uip_callback(uip_tcp_appstate_t *s)
{
  if (uip_connected()) {
    //TD("connected");

    // We want to store some data in our connections, so allocate some space
    // for it.  The app_data_t struct is defined in a separate .h file,
    // due to the way the Arduino IDE works.  (typedefs come after function
    // definitions.)
    app_data_t *d = (app_data_t *)malloc(sizeof(app_data_t));
    //memset(d, 0, sizeof(*d));
    d->state = 0;

    // Save it as SerialIP user data so we can get to it later.
    s->user = d;

    // The protosocket's read functions need a per-connection buffer to store
    // data they read.  We've got some space for this in our app_data_t
    // structure, so we'll tell uIP to use that.
    PSOCK_INIT(&s->p, d->input_buffer, sizeof(d->input_buffer));
  }

  // Call/resume our protosocket handler.
  handle_connection(s, (app_data_t *)s->user);

  // If the connection has been closed, release the data we allocated earlier.
  if (uip_closed()) {
    if (s->user) free(s->user);
    s->user = NULL;
    TD("closed");
  }
}
#endif // USE_SERIALIP

#else // USE_SERVER
// client
static struct _app_data_t {
  struct psock p;
  char input_buffer[25];
} s0, *s = &s0, *d = &s0;

unsigned char connect_server(uip_ipaddr_t *remote_server, int port)
{
  struct uip_conn *conn;

  // Open a connection to the app server on TCP port.
  conn = uip_connect(remote_server, HTONS(port));
  if (conn == NULL) {
    // Too many concurrent outgoing connections.  Should never happen
    // unless you have multiple connections open at the same time.
    TD("Too many c'ns   ");
    return 0;
  }

  // If we're here then uip_connect() was able to schedule the connection.
  // The actual connect attempt will happen later, and uip_callback will
  // be notified when it succeeds.

  // Allocate the input buffer, like in the Hello World example.
  PSOCK_INIT(&s->p, d->input_buffer, sizeof(d->input_buffer));

  return 1;
}

void app_done(int status)
{
  // This is a placeholder function that will be called when the e-mail
  // transmission is complete.  status will be 0 on success, or nonzero
  // if there was a failure.
  if (status) {
    char msg[] = "Failure code    ";
    msg[13] = '0' + status;
    TD("%s", msg);
  } else {
    TD("%s", "app done :-)   ");
  }
}


void setup_app(void)
{
  // Listen for incoming connections on TCP port IP_PORT.  Each incoming
  // connection will result in the uip_callback() function being called.
  uip_ipaddr_t app_server;
#define SET_IP(var, ip)  uip_ipaddr(var, ip)
  SET_IP(app_server, IP_REMOTE);
  connect_server(&app_server, IP_PORT);

  TD("connect to: %s", "addr: 10.1.1.2");
}

// This is the "thread" that sends the actual mail.  It returns when the
// time comes to wait for a packet to be acknowledged so that other work
// can be done, then uip_callback() calls the function again when more
// IP data arrives.  The PSOCK_* macros take care of continuing execution
// where it left off on subsequent calls.
static PT_THREAD(app_thread(void))
{
  static const char *eol = "\r\n";
  PSOCK_BEGIN(&s->p);

  TD("Wait for banner %s", "");
  PSOCK_READTO(&s->p, '\n');

  if (strncmp(d->input_buffer, "220", 3) != 0) {
    PSOCK_CLOSE(&s->p);
    TD("Banner had error");
    app_done(2);
    PSOCK_EXIT(&s->p);
  }

#if 0
  TD("Sending HELO to %s", IP_HOSTNAME);
  PSOCK_SEND_STR(&s->p, "HELO " IP_HOSTNAME MSG_EOL);

  TD("Wait for HELO %s", "ok");
  PSOCK_READTO(&s->p, '\n');

  if (d->input_buffer[0] != '2') {
    PSOCK_CLOSE(&s->p);
    app_done(3); // HELO error
    PSOCK_EXIT(&s->p);
  }
  TD("HELO accepted! %s", "");
#endif // 0

  TD("READ %s", "...");
  PSOCK_SEND_STR(&s->p, "READ" MSG_EOL);

  PSOCK_READTO(&s->p, '\n');
  if (d->input_buffer[0] != '3') { // note different response code
    PSOCK_CLOSE(&s->p);
    app_done(7); // READ failed
    PSOCK_EXIT(&s->p);
  }
  TD("Got READ: %s", d->input_buffer);

  TD("Set UNIX Time %d", 1539859388);
  PSOCK_SEND_STR(&s->p, "SETTIME 1539859388" MSG_EOL);
  TD("Wait for SETTIME ok");
  PSOCK_READTO(&s->p, '\n');
  if (d->input_buffer[0] != '2') {
    PSOCK_CLOSE(&s->p);
    app_done(3); // SETTIME error
    PSOCK_EXIT(&s->p);
  }
  TD("SETTIME accepted %s", "");

  TD("QUIT %s", "...");
  PSOCK_SEND_STR(&s->p, "QUIT" MSG_EOL);

  PSOCK_CLOSE(&s->p);
  app_done(0);

  PSOCK_END(&s->p);
}

// This is the uIP callback.  It is called whenever an IP event happens
// (which includes regular timer events.)  It "resumes" the app_thread()
// function so that the Arduino doesn't get stuck in this function waiting
// for packets to be acknowleged.
void uip_callback(uip_tcp_appstate_t *s)
{
  if (uip_closed()) {
    return;
  }
  if (uip_aborted() || uip_timedout()) {
    //app_done(1);
    return;
  }

  // Start (or resume) the app communication.
  app_thread();
}
#endif // SERVER

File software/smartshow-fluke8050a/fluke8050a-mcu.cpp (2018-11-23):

/**
 * \file    fluke8050a-mcu.cpp
 * \brief   Fluke 8505a MCU pins interface
 *   adjust the TFT_8050A of Michael Damkier
 */


/*
TFT_8050A.ino

TFT display implementation for Fluke 8050A multimeter

Thank you to Adafruit for the following hardware and supporting software
Adafruit #296 Atmega32u4 Breakout Board
  http://www.adafruit.com/products/296
Adafruit #1480 2.2" TFT LCD display - ILI9340
  http://www.adafruit.com/products/1480

Michael Damkier
Hamburg, Germany
(michael@vondervotteimittiss.com)

*/

#if ARDUINO >= 100
#include <Arduino.h>
#else
#include <WProgram.h>
#endif

#include <SPI.h>

//#define TD(a) Serial.println(a)
#define TD(a)


#ifdef __AVR__

#include "fluke8050a-mcu.h"
#include "fluke8050a-show.h"

// bit clear/set/invert/test
#define clear_bit(b,bit) (b &= ~_BV(bit))
#define set_bit(b,bit) (b |= _BV(bit))
#define invert_bit(b,bit) (b ^= _BV(bit))
#define test_bit(b,bit) ((b & _BV(bit)) != 0)


fluke8050a_reads_t g_fluke8050a_data = {
    0, 0, {0}, {0}
};

// read what the LCD shows.
int
fluke8050a_get_data(fluke8050a_reads_t * ret_data)
{
    memset(ret_data, 0, sizeof(*ret_data));
    //if (g_fluke8050a_data.flags & FLUKE8050A_MASK_VALID) {
        memmove(ret_data, &g_fluke8050a_data, sizeof(g_fluke8050a_data));
        return 0;
    //}
    return -1;
}

const char *
fluke8050a_mode2cstr(uint8_t unit) {
#define CASE(a) case MODE_ ## a: return #a
  switch (unit) {
  //CASE(NONE);
  case MODE_NONE: return "NA";
  CASE(DC);
  CASE(AC);
  CASE(REL);
  }
#undef CASE
  return "?Mode?";
}

const char *
fluke8050a_unit2cstr(uint8_t unit) {
#define CASE(a) case UNIT_ ## a: return #a
  switch (unit) {
  //CASE(NONE);
  case UNIT_NONE: return "NA";
  CASE(V);
  CASE(mV);
  case UNIT_microA: return "uA";
  CASE(mA);
  CASE(Ohm);
  CASE(kOhm);
  CASE(MOhm);
  CASE(dB);
  CASE(mS);
  CASE(nS);
  CASE(Z);
  }
#undef CASE
  return "?Unit?";
}

// convert the current readings of structure fluke8050a_reads_t to string
int
fluke8050a_reads2desc(fluke8050a_reads_t *g_reads, char *buf, size_t sz_buf)
{
  //TD("fluke8050a_get_desc()...");
#if DEBUG
  snprintf_P(buf, sz_buf, PSTR("%02X(%s%s%s%s), %02X(%s), %02X(%s), (%s, %s, %s), func=%02X, rang=%02X, mode=%02X, bplevel=%02X, hvlevel=%02X, PINB=%02X")
    , g_reads->flags
    , ((g_reads->flags & FLUKE8050A_MASK_HIGHVOL)?"HV,":"")
    , ((g_reads->flags & FLUKE8050A_MASK_LOWBAT) ?"BAT,":"")
    , ((g_reads->flags & FLUKE8050A_MASK_RELATIVE) ?"REL,":"")
    , ((g_reads->flags & FLUKE8050A_MASK_VALID) ?"":"invalid")
    , g_reads->mode
    , fluke8050a_mode2cstr(g_reads->mode)
    , g_reads->unit
    , fluke8050a_unit2cstr(g_reads->unit)
    , g_reads->digits
    , g_reads->digits_z
    , g_reads->digits_rel
    , g_reads->func
    , g_reads->rng
    , g_reads->bp
    , g_reads->hv
    , g_reads->vPINB
    );
#else
  snprintf_P(buf, sz_buf, PSTR("%02X(%s%s%s%s), %02X(%s), %02X(%s), (%s, %s, %s)")
    , g_reads->flags
    , ((g_reads->flags & FLUKE8050A_MASK_HIGHVOL)?"HV,":"")
    , ((g_reads->flags & FLUKE8050A_MASK_LOWBAT) ?"BAT,":"")
    , ((g_reads->flags & FLUKE8050A_MASK_RELATIVE) ?"REL,":"")
    , ((g_reads->flags & FLUKE8050A_MASK_VALID) ?"":"invalid")
    , g_reads->mode
    , fluke8050a_mode2cstr(g_reads->mode)
    , g_reads->unit
    , fluke8050a_unit2cstr(g_reads->unit)
    , g_reads->digits
    , g_reads->digits_z
    , g_reads->digits_rel
    );
#endif
}


/*
function and range switch settings
*/

/*
meter truth table (at 3870 pins)

      RNGa    RNGb    RNGc
.2      H       H       L
2       L       H       H
20      H       L       H
200     L       L       H
2000    H       H       H
20M     L       L       L
2mS     L       H       L
200nS   H       L       L

        Fa      Fb      Fc      Fd
AC      H       x       x       x
V       x       H       L       x
mA      x       L       H       x
kOhm    x       L       L       x   (also depends on RNG)
dB      x       H       H       x
S       x       L       L       x   (also depends on RNG)
REL     x       x       x       L

*/

/*
func truth table

                  v
        F F F F   a
        c a d b   l

V       0 x x 1   1
mA      1 x x 0   8
kOhm    0 x x 0   0   (also depends on RNG)
db      1 x x 1   9
S       0 x x 0   0   (also depends on RNG)
AC      x 1 x x
REL     x x 1 x

*/

#define BIT_Fb    0
#define BIT_Fd    1
#define BIT_Fa    2
#define BIT_Fc    3

#define FUNC_V    1
#define FUNC_A    8
#define FUNC_Ohm  0
#define FUNC_dB   9

/*
rng truth table

          R R R
          N N N   v
        B G G G   a
        T a b c   l

.2      x 1 1 0   6
2       x 0 1 1   3
20      x 1 0 1   5
200     x 0 0 1   1
2000    x 1 1 1   7
20M     x 0 0 0   0   (also set Z in dB function)
2mS     x 0 1 0   2
2nS     x 1 0 0   4
BT      1 x x x

*/

#define BIT_RNGc  0
#define BIT_RNGb  1
#define BIT_RNGa  2
#define BIT_BT    3

#define RNG__2    6
#define RNG_2     3
#define RNG_20    5
#define RNG_200   1
#define RNG_2000  7
#define RNG_20M   0
#define RNG_Z     0
#define RNG_mS    2
#define RNG_nS    4



// 8050A scancode buffer (ISR)
volatile uint8_t scanCodes[ NUM_STROBES ];

// strobe timing (ISR)
volatile boolean strobeCycle = false;

void
fluke_raw_init(struct fluke_raw_t *r)
{
    int i;
    memset(r, 0, sizeof(*r));
    for(i = 0; i < NUM_DIGITS; i ++) {
        r->digits[i] = DIGIT_SPACE;
        r->relDigits[i] = DIGIT_SPACE;
        r->zDigits[i] = DIGIT_SPACE;
    }
    r->zDigits[2] = 6;
    r->zDigits[3] = 0;
    r->zDigits[4] = 0;

    r->sign = SIGN_NONE;
    r->rSign = SIGN_NONE;

    r->mode = MODE_NONE;
    r->rMode = MODE_NONE;

    r->unit = UNIT_NONE;
    r->rUnit = UNIT_NONE;

    r->baseUnit = BASEUNIT_undef;
    r->rBaseUnit = BASEUNIT_undef;

    // operation flags
    r->rel = false;
    r->relValid = false;
    r->hv = false;

    // decimal point position
    r->dp = DP_NONE;
    r->dpr = DP_NONE;
}

struct fluke_raw_t fluke_raw;

/*
PIN ASSIGNMENTS
*/

#if defined (__AVR_ATmega32U4__)
// ATMega32U4

// TFT display communication pins
#define PIN_RST     5   //PINC6
#define PIN_DC      13  //PINC7
// Hardware SPI pins are specific to the Arduino board type and
// cannot be remapped to alternate pins.  For Arduino Leonardo (ATmega32u4),
// pin 16 = MOSI, pin 14 = MISO, pin 15 = SCK.


// 8050A strobe lines
#define BIT_ST0         PINB7 // (PCINT7)
#define BIT_ST1         PINB6 // (PCINT6)
#define BIT_ST2         PINB5 // (PCINT5)
#define BIT_ST3         PINB4 // (PCINT4)
#define BIT_ST4         PINE6 // (INT.6)

// 8050A scancode lines
#define BIT_HV          PINF0
#define BIT_DP          PINF1
#define BIT_Z           PINF4
#define BIT_Y           PINF5
#define BIT_X           PINF6
#define BIT_W           PINF7
#define BIT_1           BIT_Z
#define BIT_PLUS        BIT_X
#define BIT_MINUS       BIT_W
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

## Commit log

2018-10-29 Add mcufont driver
2018-10-29 add Adafruit TFT driver
2018-10-29 update URL
    [fluke8050-screen-avr.sch]
2018-11-16 update the 32u4 info
    [fluke8050-screen-arm.sch, fluke8050-screen-avr.sch]
2018-11-16 update the interrupt routines for atmega32u4.
2018-11-17 fix TFT screen for atmega32u4
    [conf-func.h, conf-tft.h]
2019-06-16 update the sch
    [fluke8050-screen-arm.sch, fluke8050-screen-avr.sch, fluke8050-screen.sch]
